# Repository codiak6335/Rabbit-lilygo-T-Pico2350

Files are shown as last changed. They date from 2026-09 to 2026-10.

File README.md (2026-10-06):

# Rabbit controller

The LilyGO T-Pico2350 is being replaced by two separate boards:

- Waveshare RP2350B Plus W, which will run the workout controller.
- Waveshare ESP32-C6-LCD-1.9, which will provide the display and network interface. The connected ESP identifies as an ESP32-C6FH8 with 8 MB flash. USB identifies the chip, but does not distinguish the LCD board variant.

## Inter-board UART wiring

The boards are already connected with three wires. Pin numbers in the left column are **physical header positions** on the RP2350 board, not GPIO numbers.

| RP2350B Plus W | Signal direction | ESP32-C6-LCD-1.9 |
| --- | --- | --- |
| Pin 1, GP0 / UART0 TX | RP2350 → ESP32-C6 | GPIO17 / UART RX |
| Pin 2, GP1 / UART0 RX | ESP32-C6 → RP2350 | GPIO16 / UART TX |
| Pin 3, GND | Common ground | GND |

The existing connection contains TX, RX, and ground; no RTS/CTS wires were specified. See the [Pico-compatible pinout](https://datasheets.raspberrypi.com/pico/Pico-2-Pinout.pdf) and [ESP32-C6-LCD-1.9 documentation](https://docs.waveshare.com/ESP32-C6-LCD-1.9).

## Printable enclosure

The [Rev D resin-window housing](mechanical/resin_housing/README.md) includes PETG body,
lid frame, window retainer and integral PCB standoffs, plus closed and split-wrap TPU strain
relief STLs for 2.3, 3, 3.5 and 4 mm cable jackets. It uses a cast clear resin
window, a silicone cord lid seal and two oversized cable entries for adhesive
sealing. Editable dimensions, print-fit coupons and assembly instructions are
included. The 82 × 128 × 33.1 mm prototype matches the `rev_d_case` 60 × 100 mm
PCB and its offset mounting hole, with the display centered, LED cable entry at
the top and power cable entry at the bottom. The captured KiCad reference is
checked during regeneration. Physical fit and splash/submersion qualification
remain to be performed.

## Current firmware status

The checked-in C++ firmware now targets this three-wire link. The RP2350 uses UART0 on GP0/GP1 without the LilyGO I²C expander startup; the ESP32-C6 uses UART0 on GPIO16/GPIO17 and sends its console output through USB Serial/JTAG. The ESP currently joins the provisioned `beaver` network and keeps `Rabbit-Test-6905` available as a fallback AP. The LCD shows live workout status and the Beaver DHCP address. The checked-in Coach On Deck browser UI is served at `/`, with repeatable pace/sprint set commands and NVS-backed saved sets; `/test` retains the manual diagnostics page. DeckScript plan transfer and surge pacing are flashed and passed paired-device HTTP/UART smoke tests; full browser and pool-side acceptance, external LEDs/audio, protected configuration editing, and hardware qualification remain unfinished. See [firmware/README.md](firmware/README.md) for build and diagnostic commands.

On this development host, the RP2350 appears as `/dev/ttyACM0` and the ESP32-C6 as `/dev/ttyACM1`. With the C++ firmware flashed, their stable serial-device names are:

```text
/dev/serial/by-id/usb-Raspberry_Pi_Pico_509E0DF26DCF56B6-if00
/dev/serial/by-id/usb-Espressif_USB_JTAG_serial_debug_unit_CC:BA:97:F2:69:04-if00
```

The 2026-09-25 paired-device smoke test passed: the ESP32-C6 USB console
reported `Rabbit RP2350 UART link: ready`, and the RP2350 USB `status` command
reported decoded UART requests and responses. The latest station/AP test joined
`beaver` at `192.168.0.178` and returned HTTP 200 for `/`, the browser assets,
pool and saved-set data, and `/api/set-status`. That DHCP address may change;
use the address displayed on the LCD. The fallback AP remains at
`http://192.168.4.1/` after joining `Rabbit-Test-6905`.

## Bluetooth speaker audio

Open **Deck tools → Audio output** in the ESP32 web interface. Audio uses the
same menu-row and Back-button navigation as the other settings.
Choose **Bluetooth speaker** to replace the buzzer or **Buzzer + speaker** for
both outputs. Output selection applies immediately. The volume slider applies
changes automatically as you move it; there is no Save button. Volume is 0–100
and saved volume is preserved. A GPIO active buzzer has a fixed level and is muted
at 0%.

The screen uses a familiar Bluetooth device picker: **My devices** keeps up to eight saved
speakers, including ones that are off or disconnected. Tap a saved device to reconnect
without scanning. Selecting another speaker, closing the page, or restarting either
board keeps all saved devices and their sound confirmations. **Forget** removes only
the device beside that control; forgetting an inactive device keeps the active speaker connected. To add a speaker:

1. Tap **Add speaker** to show **Nearby devices** and pairing instructions.
2. Power on the speaker and hold its Bluetooth button until the pairing indicator
   flashes. Disconnect it from your phone if needed. Tap **Scan** when ready.
   [MEGABOOM 3 pairing instructions](https://support.logi.com/hc/en-gb/articles/18601350410775-Getting-Started-MEGABOOM-3).
3. Tap the desired device in the list to connect directly. Bluetooth addresses
   distinguish devices with identical names; unnamed audio devices can also connect.
4. Once **Connected**, tap **Test 3 beeps**. Adjust volume and test again if needed.
5. Tap **I heard them** to record your sound confirmation. **I didn’t hear them**
   shows guidance to raise volume and repeat the test without confirming.

A scan searches Bluetooth Classic audio devices for about 20 seconds, then resolves
missing names, with a 45-second overall limit. It holds up to 16 devices. **Scan again**
starts fresh; **Stop scan** keeps the current results. Scanning keeps the existing
speaker association and output settings. A rejected Connect request changes neither
output nor volume. An unsuccessful or cancelled new connection retains the previous
saved speaker. **Close** or the screen's Back button stops discovery and cancels an unfinished
connection. Tap the saved speaker to reconnect. An unavailable saved speaker's
automatic reconnect does not block adding another device.
Setup/testing require an idle workout; discovery, connection, and active tests block
workout start. Errors remain visible until the next action.

Bluetooth Classic A2DP/SBC and AVRCP volume control run on the **RP2350B Plus W's CYW43439**.
The ESP32-C6 serves the UI and forwards commands over the existing UART link.
The workout's existing Audio choice gates the same beep signal for both outputs.
Bluetooth speaker buffering adds playback delay; pool-side timing still needs qualification.
While Bluetooth output is connected and unmuted, the RP2350 keeps A2DP streaming and
sends a quiet one-second 80 Hz maintenance pulse every 30 seconds, starting on connection.
The pulse is 1/128 of the workout tone's amplitude and fades in and out to avoid clicks.
It also runs between reps with five- or ten-minute gaps and while idle, to address
speakers that power down despite receiving silent packets. Workout/test beeps take
priority. Volume 0 mutes the pulse; Off, buzzer-only output, or Disconnect stops it.
The exact signal level needed to reset a speaker's inactivity timer is model-dependent;
the MEGABOOM's physical long-gap check remains to be verified. The keep-alive build
is flashed on the RP2350. Three native suites pass, including eleven-minute PCM
checks with five- and ten-minute rep gaps; a round trip through the actual Bluedroid
SBC encoder/decoder preserves the quiet pulse. Live UART/HTTP checks retained both
saved speakers and 49% volume, with the Samsung streaming and no fault recovery reported.
The buzzer remains available if a verified `RABBIT_AUDIO_PIN` is configured.
The development build has that pin disabled.

Output mode, volume, the selected speaker, the saved-device list, each device's sound
confirmation, and pairing keys persist on the RP2350. A full saved-device list does
not evict older speakers: forget one before adding another. Upgrading imports earlier
pairing keys, including devices replaced by the old single-speaker setting. Those keys
contain addresses only; names are recovered when the devices are reachable, and an
old confirmation overwritten by the previous firmware cannot be reconstructed. Settings saves wait until the workout is idle; the API reports pending
saves and the speaker's acknowledged volume. A saved speaker reconnects automatically
while idle when Bluetooth output is enabled. Disconnect suppresses reconnect until
requested again (or the controller restarts); Forget removes the association and its
link key. Confirmation requires a completed test on the currently streaming speaker;
a disconnected or interrupted test cannot be confirmed.

ESP32 HTTP API (commands return current audio status; Devices returns a discovery page):

| Method | Route | Body / query |
| --- | --- | --- |
| GET | `/api/audio/status` | none |
| GET | `/api/audio/saved?offset=0` | saved devices, offset 0–8; up to four results per page |
| POST | `/api/audio/config` | `{"mode":"bluetooth","volume":50}`; modes `off`, `buzzer`, `bluetooth`, `both` |
| POST | `/api/audio/scan` | empty |
| GET | `/api/audio/devices?offset=0` | offset 0–16; up to four results per page |
| POST | `/api/audio/scan-stop` | empty |
| POST | `/api/audio/connect` | `{"address":"C0:28:8D:DC:C9:3D","mode":"bluetooth","volume":49}`; scanned or saved address, mode `bluetooth` or `both` |
| POST | `/api/audio/test` | empty |
| POST | `/api/audio/confirm` | empty; only after a completed speaker test |
| POST | `/api/audio/disconnect` | empty |
| POST | `/api/audio/forget` | `{"address":"C0:28:8D:DC:C9:3D"}` removes that saved speaker; empty body removes the selected speaker |
| POST | `/api/audio/pair` | Legacy exact-name pairing; `{"name":"MEGABOOM 3"}`, empty body uses that name |

Status includes `mode`, `volume`, `connection`, `name`, `address`, `supported`,
`buzzerAvailable`, `paired`, `volumeConfirmed`, `actualVolume`, `testActive`,
`settingsPending`, `soundConfirmed`, `workoutRunning`, and `lastError`.
`actualVolume` is null until acknowledged. Device pages include `scanning`, `full`,
`total`, `devices` (name/address/rssi), and `next` (next offset or null). Saved pages
include `total`, `full`, `devices` (name/address/soundConfirmed), and `next`.
Invalid payloads return 400, unavailable/busy commands 409, unavailable Bluetooth 501,
and a failed UART exchange 503. Scan and Connect are asynchronous; poll Devices and
Status respectively. UI requests have an eight-second response timeout. Slider changes are debounced
200 ms and sent in order; the final slider value is applied even if it changes
while an earlier request is in flight. Output selections apply immediately.

The RP2350 UART API uses the existing version-1 CRC/COBS frames and Hello session.
Message IDs 12–17 remain AudioStatus, AudioConfigure, AudioPair, AudioDisconnect,
AudioTest, and AudioForget. IDs 18–22 add AudioScan, AudioDevices, AudioConnect,
AudioConfirm, and AudioScanStop. IDs 23–24 add AudioSaved and AudioForgetDevice.
Saved takes a one-byte offset; ForgetDevice takes a six-byte address. Configure carries mode/volume bytes; legacy Pair
carries 1–48 name bytes without NUL/control characters. Devices takes a one-byte
offset; Connect takes `[address[6], mode=2|3, volume=0..100]`. Other commands have
empty payloads. Success returns AudioStatus except Devices, which returns AudioDevices.
Request/session IDs are preserved; failures use the existing Reject format.
The status payload remains `[version=1, mode, volume, connection, flags, actualVolume,
lastError, nameLength, address[6], name[nameLength]]`. Connection values 0–6 are
disabled, idle, scanning, connecting, connected, streaming, error. Flag bits 0–7
are supported, buzzer available, paired, volume confirmed, test active, save pending,
sound confirmed, workout running. Unknown actual volume is 255.
Devices payload is `[version=1, scanning, full, total, offset, count, records...]`;
Saved uses the same page header with scanning=0 and replaces RSSI with a 0/1 sound-confirmed byte.
Discovery records are `[nameLength, address[6], signedRssi, name[nameLength]]` (RSSI 0 means
unknown). Four maximum-length records fit in 230 bytes. UART retries reuse IDs and
cannot restart scans, connections, tests, or confirmations. Version-2 audio settings
retain compatibility with previously saved version-1 settings and Bluetooth keys.

Radio GPIOs are GP36 (enable), GP37 (data/host wake), GP38 (CS), and GP39 (clock),
verified against the [Waveshare schematic](https://files.waveshare.com/wiki/RP2350B-Plus-W/RP2350B-Plus-W.pdf).
The LED output uses PIO1 to keep its low GPIO range separate from the radio's high GPIOs.
Large LED/UART buffers reside in static RAM; the foreground stack reserves 4 KiB.
The radio uses foreground CYW43 polling so Bluetooth callbacks and UART commands share
one execution context. Both AVRCP roles are initialized to handle the speaker's control
messages. A four-second watchdog recovers a stalled controller; USB `status` reports
the last recovery stage and captured fault location.
Pairing/settings use the SDK's two flash TLV banks near the end of the 16 MiB flash;
avoid erasing that storage when preserving saved audio settings.

The 2026-10-04 saved-device build is installed on both boards. Native protocol/workout
checks pass (2/2), including saved-list storage validation, pagination, retaining
multiple speakers, and forgetting one device without removing another. Mobile browser
checks cover retained device lists, reconnecting without a scan, per-device Forget,
automatic volume/output changes, connection errors, sound confirmation, workout gating,
scan cancellation, and Back navigation. The installed ESP32 UI displays both the
Samsung Soundbar MS650 and the recovered MEGABOOM pairing, with separate Connect/Forget
controls; the disconnected MEGABOOM remains listed after a page reload. A further
RP2350 reboot retained both records, the Samsung sound confirmation, selected speaker,
and 49% volume; the soundbar resumed streaming. The MEGABOOM's old link key contains
its address but not the name or confirmation overwritten by the old single-device
setting. Earlier live checks verified automatic MEGABOOM volume changes and real
discovery/cancellation. Pool-side latency remains to be qualified. The ESP32 address
for these checks was `http://192.168.0.166/`; use the current LCD address if DHCP changes it.

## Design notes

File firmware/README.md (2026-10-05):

# Native firmware

This directory contains the in-progress production replacement for the
MicroPython controller. The existing Python implementation remains the
behavioral reference until hardware qualification is complete.

## Layout

- `core/`: allocation-free-at-run-time workout validation, pool geometry, and
  scheduler. It has no SDK, file, socket, or sleep dependency.
- `protocol/`: bounded COBS/CRC UART frames and transactional plan-transfer
  buffer shared by the two processors.
- `host/`: desktop executable using the same portable core.
- `rp2350/`: Pico SDK application, local-stop loop, and WS2812 PIO/DMA output.
- `esp32/`: ESP-IDF application boundary for the C6 HTTP/network process.

## Build the portable code

Until CMake is installed, the host checks can run directly with the compiler:

```sh
mkdir -p /tmp/rabbit-native-build
c++ -std=c++17 -Wall -Wextra -Wpedantic -Wconversion -Wshadow \
  -Ifirmware/core/include -Ifirmware/protocol/include \
  firmware/core/src/pool_geometry.cpp firmware/core/src/workout_engine.cpp \
  firmware/protocol/src/framing.cpp firmware/protocol/src/workout_service.cpp \
  tests/native/test_main.cpp \
  -o /tmp/rabbit-native-build/rabbit_native_tests
/tmp/rabbit-native-build/rabbit_native_tests
```

With CMake, build the same targets from the repository root using the supplied
host presets:

```sh
cmake --preset host-debug
cmake --build --preset host-debug
ctest --test-dir build/host-debug --output-on-failure
```

Run the sanitizer configuration separately:

```sh
cmake --preset host-sanitize
cmake --build --preset host-sanitize
ctest --test-dir build/host-sanitize --output-on-failure
```

## RP2350 build

Use the exact Pico SDK and ARM toolchain listed in `toolchains.lock`. The external Rabbit
LED and audio wiring is unverified, so both are disabled by default. Supplying a
pin is a board-qualification step, not a default production configuration.

```sh
cmake -S firmware/rp2350 -B build/rp2350 -G Ninja \
  -DPICO_SDK_PATH=/absolute/path/to/pico-sdk
cmake --build build/rp2350
```

The project defaults to the Waveshare RP2350B Plus W board profile in
`rp2350/boards/`. The generated UF2 appears under `build/rp2350`.
External LED, audio, and local-stop pins remain disabled until their wiring is
verified.
The Pico SDK's generated PIO header is compiled as C++20; the portable engine
and RP2350 application sources remain C++17.

## RP2350 USB diagnostics and UART service

The RP2350 image exposes a USB CDC console after boot. Connect at `115200` baud
and expect `Rabbit RP2350 diagnostic firmware ready`. The bounded commands are
`help`, `status`, `led`, `audio`, and `off`. `led`, `audio`, and local stop
intentionally report unavailable until their physical pins are verified and
supplied at build time. The same image runs the bounded UART0 service at
115200 baud. It accepts a
session handshake plus `PrepareBegin`, `Start`, `Stop`, `Cancel`, and `Status` frames;
COBS framing, CRC, request IDs, and session IDs are enforced. The RP2350 uses
UART0 on physical header pins 1/2 (GP0 TX/GP1 RX), connected to ESP32-C6
GPIO17 RX/GPIO16 TX, with a shared ground on RP2350 header pin 3. No hardware
flow control is wired. The initial
prepare payload is 13 bytes: flags, followed by big-endian `distance_mm`,
`target_ms`, and `interval_ms` fields. The 21-byte set payload adds big-endian
repetitions, final-rep target, and surge percentage. This supports 1–256
whole-pool pace repetitions and a continuous sprint loop. A compiled DeckScript
plan uses checksummed `PrepareBegin`/`PrepareChunk`/`PrepareCommit` frames and a
bounded 12 KiB binary plan. The Pico validates and runs swim, rest, and activity
steps, including continuous loops, per-rep progression, surge, and negative
splits. The base 28-byte UART status frame includes remaining milliseconds,
cycle, set count, current distance and target, and a continuous-mode flag;
DeckScript status appends the current step, strategy, swim count, and bounded
name/label text. External LED pin assignment and calibrated physical geometry
are still unverified.

## ESP32-C6 build

Install and source the exact ESP-IDF release in `toolchains.lock`, then build
in this directory:

```sh
cd firmware/esp32
idf.py set-target esp32c6
idf.py build
```

The ESP application configures UART0 on TX GPIO16/RX GPIO17 without hardware
flow control. Its console uses USB Serial/JTAG so application logs do not enter
the interprocessor link. At startup it probes RP2350 status and reports the
result on its USB console. The onboard 170×320 ST7789V2 LCD displays the live
workout phase, distance, rep count, countdown, and IP address. The ESP polls
RP2350 status for this display and the webpage's set details, so an ESP restart
does not reset the visible rep total. It establishes/re-establishes a session and forwards the
bounded vertical slice through `POST /api/workout/prepare`,
`POST /api/workout/start`, `POST /api/workout/stop`, the legacy quick-set
`GET /prep`, `GET /start`, `GET /startsprint`, `GET /stop`, `GET /cancel-prep`,
and `GET /api/set-status`. The modern prepare route accepts an optional JSON object with
`distanceMm`, `targetMs`, `intervalMs`, `audio`, `waitForInterval`, and
`direction: "far-to-near"`; omitted numeric values select a 25-yard,
30-second test swim. A transport failure returns HTTP 503, never a false
success.

The checked-in Coach On Deck page is embedded at `/`; the former manual test
page is at `/test`. CSS, JavaScript, pool definitions, and the DeckScript prompt
are served from the firmware image. Saved sets begin with the checked-in
`db/sets.json` and subsequent browser edits are validated and committed to
ESP NVS. Pool and Wi-Fi editing intentionally return 501; Wi-Fi credentials
are never served by the browser API. Compiled DeckScript 2 plans from the
browser are validated against the embedded pool list and transferred to the
Pico; unsupported or malformed plans return an error rather than a default
swim. The app uses the 1500 KiB single
app partition; upgrading an earlier 1 MiB build requires flashing its new
partition table alongside the app, without erasing NVS.

The ESP currently joins the provisioned `beaver` network while keeping the
`Rabbit-Test-6905` AP available as a fallback at `http://192.168.4.1/`. The
LCD shows the station's DHCP address after connection; on 2026-09-25 this was
`192.168.0.178`, but the address may change. To
provision an existing Wi-Fi profile without putting its password in source or
on the command line, run this from the repository root (requires `pyserial`):

```sh
python3 tools/provision_esp_wifi.py \
  --port /dev/serial/by-id/usb-Espressif_USB_JTAG_serial_debug_unit_CC:BA:97:F2:69:04-if00 \
  --ssid beaver
```

The tool reads `db/wifi.json`, sends the selected credentials over USB, and
stores them in the ESP's `rabbit_net` NVS namespace. The current station/AP
build loads those credentials on boot, updates the LCD when DHCP assigns an
address, and reports the address
as `Rabbit Wi-Fi connected: ...` on USB. The browser UI is then available
at `http://<that-address>/`. Do not log or commit additional credential
copies when provisioning another device.

Full Wi-Fi lifecycle, protected settings, physical LED/audio wiring,
and phone-browser/pool-side DeckScript acceptance still remain
before this can replace MicroPython. See `../docs/cpp-migration-plan.md` for
the acceptance gates and recovery rules.

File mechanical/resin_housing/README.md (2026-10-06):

# Rev D housing with cast-resin viewing lid

Printable housing for the **`rev_d_case` 60 × 100 mm carrier PCB**, with a clear resin window centered over the ESP32 display. The assembled shell is **82 × 128 × 33.1 mm**, excluding the cable boots. Viewed with the screen facing you, the **LED cable exits the top end** and **power enters the bottom end**. Both glands share the case and display centreline at **X = 30 mm**, with internal leads running to J6 and J5. Both entries accept the same relief neck; choose reliefs for **2.3, 3.0, 3.5 or 4.0 mm complete cable jacket diameters**.

This replaces the earlier 88 × 58 mm compact-carrier housing. PCB outline, mounting holes and socket positions are checked against the captured [Rev D KiCad board](reference/Rabbit_Carrier_RevD.kicad_pcb). Module heights, actual LCD datum and sealing still require first-article checks. **Physical fit and leak testing have not been performed; it has no verified waterproof/IP rating.** Print the coupons first, then qualify frequent splashes and brief submersion up to 3 ft.

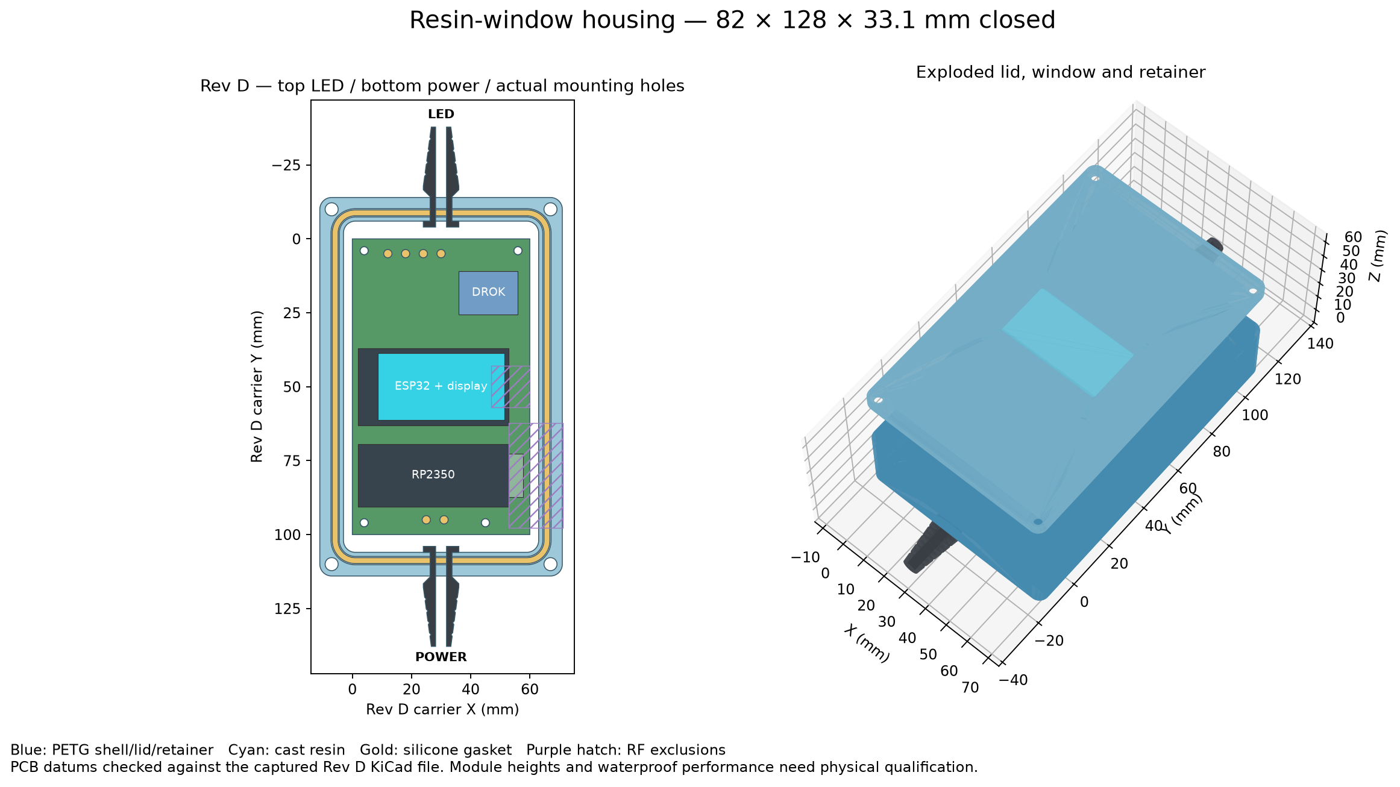
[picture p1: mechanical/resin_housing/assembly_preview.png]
Assembly and plan


## Files and print quantities

All STL dimensions are millimetres. Each STL is already placed on the print bed in its intended orientation. Import at 100% scale.

| Part | Quantity | Material / purpose |
| --- | ---: | --- |
| [Body](stl/body_petg.stl) | 1 | PETG; open side up; blind insert pockets, cord groove and four integral Rev D standoffs |
| [Lid frame](stl/lid_frame_petg.stl) | 1 | PETG; outside face down; doubles as the resin casting frame |
| [Window retainer](stl/window_retainer_petg.stl) | 1 | PETG; sealant groove faces up in the slicer, toward the lid in assembly |
| [Cable entry coupon](stl/cable_entry_fit_coupon_petg.stl) | 1 optional | PETG; reproduces the horizontal bore and 8 mm wall thickness |
| [Resin casting coupon](stl/resin_cast_fit_coupon_petg.stl) | 1 optional | PETG; small version of the cast window flange |
| [Coupon retainer](stl/resin_coupon_retainer_petg.stl) | 1 optional | PETG; tests mechanical retention and the resin/PETG seal |
| [Unused entry plug](stl/unused_entry_plug_tpu.stl) | As needed | TPU; seal into any unused entry |
| Cable reliefs below | 1 per cable | TPU; inside flange on the bed, cable bore vertical |

| Cable jacket outside diameter | Closed relief | Split wrap relief | Nominal bore |
| --- | --- | --- | ---: |
| 2.3 mm | [STL](stl/strain_relief_2_3mm_closed_tpu.stl) | [STL](stl/strain_relief_2_3mm_split_wrap_tpu.stl) | 2.5 mm |
| 3.0 mm | [STL](stl/strain_relief_3_0mm_closed_tpu.stl) | [STL](stl/strain_relief_3_0mm_split_wrap_tpu.stl) | 3.2 mm |
| 3.5 mm | [STL](stl/strain_relief_3_5mm_closed_tpu.stl) | [STL](stl/strain_relief_3_5mm_split_wrap_tpu.stl) | 3.7 mm |
| 4.0 mm | [STL](stl/strain_relief_4_0mm_closed_tpu.stl) | [STL](stl/strain_relief_4_0mm_split_wrap_tpu.stl) | 4.2 mm |

Closed reliefs can be fitted before feeding the cable through. Split wraps open along a 0.4 mm radial seam for already terminated cables; that seam must be filled and sealed. The specified wire sizes refer to the **complete insulated jacket**, not the conductor diameter. A common jacket around multiple conductors needs its own measured relief bore.

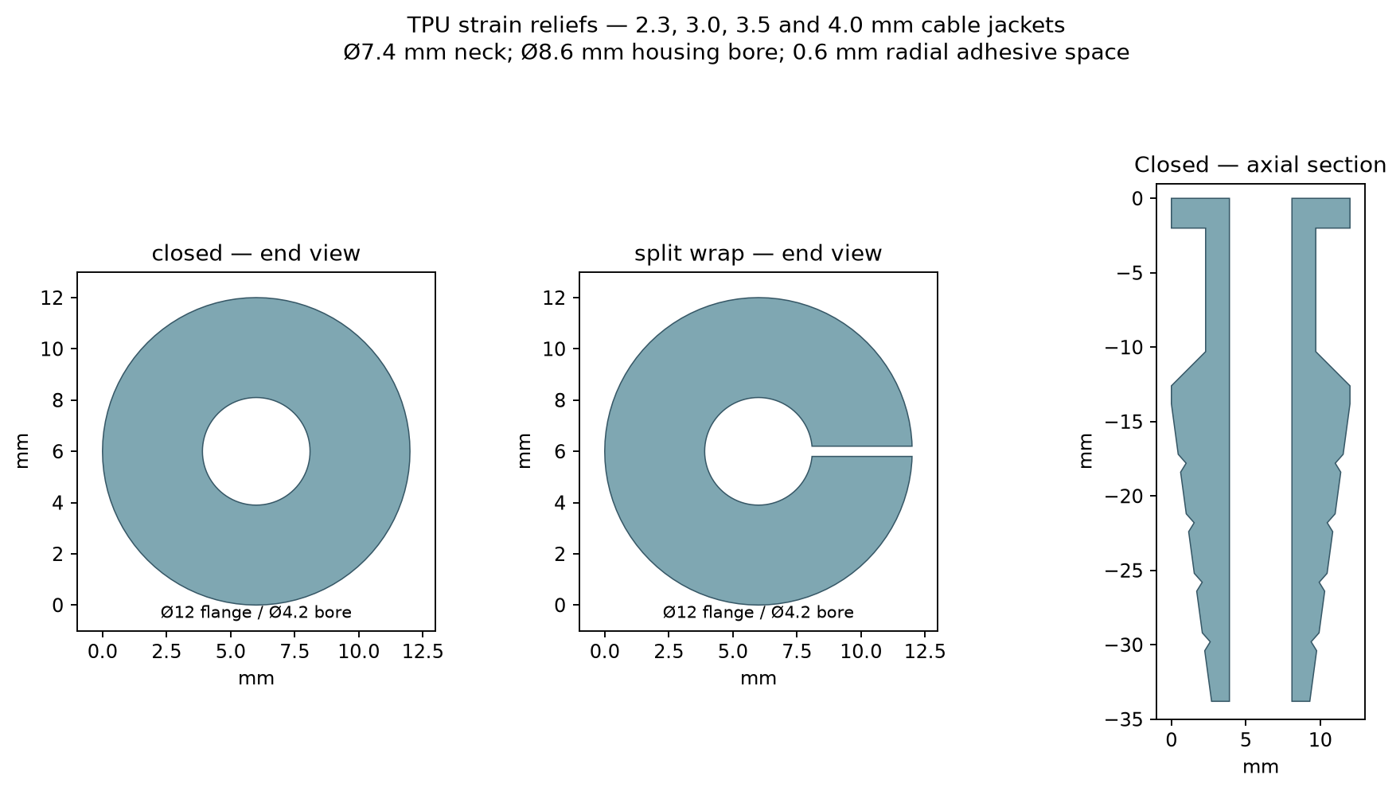
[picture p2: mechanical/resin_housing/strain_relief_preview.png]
Relief cross-sections


## Dimensions and hardware assumptions

See [dimensions.svg](dimensions.svg) for the plan. Coordinates below follow the carrier drawing: X right, Y down; Z up from the outside bottom of the enclosure.

| Feature | Nominal dimension |
| --- | --- |
| Carrier PCB | Rev D, 60 × 100 × 1.6 mm |
| PCB mounting holes | Ø2.7 mm at (4,4), (56,4), (4,96), **(45,96)** |
| Integral standoffs | Ø6 mm, 2.5 mm above the floor; Ø2.0 mm blind pilots for M2.5 plastic-tapping screws |
| PCB underside | Z = 5.5 mm; 2.5 mm clearance over the 3 mm floor |
| Space above PCB | 22 mm to lid; 20 mm under the window retainer |
| Estimated LCD front plane | 18.35 mm above PCB top; 1.65 mm below the retainer, 3.65 mm below the resin |
| Viewing opening | Rev D provisional aperture, 43.5 × 23.5 mm, corner radius 1 mm |
| Viewing opening centre | Carrier X = 30, Y = 50 mm |
| Cast resin | 4 mm thick at the viewing opening; 55.5 × 35.5 × 2.4 mm rear flange, corner radius 3 mm |
| Resin amount | About 6.3 mL net; allow for mixing/cup losses |
| Window retainer | 63.5 × 43.5 × 2 mm; continuous 1.2 mm wide × 0.6 mm deep sealant groove |
| Retainer screw centres | (11,30.25), (49,30.25), (11,69.75), (49,69.75); clear of RF exclusions |
| Cable holes | Ø8.6 mm through the 8 mm top and bottom end walls |
| LED entry | Top end (−Y), centered at X = 30; wall spans Y = −14 to −6; cable axis Z = 15 |
| Power entry | Bottom end (+Y), centered at X = 30; wall spans Y = 106 to 114; cable axis Z = 15 |
| Relief neck / collar | Ø7.4 mm neck, 8.3 mm between collar faces; Ø12 mm collars |
| Glue clearance | 0.6 mm radial gap around relief neck; 0.1 mm nominal radial gap around cable |
| Relief length | 33.8 mm total; approximately 24 mm projects outside the case |
| Main gasket | 2 mm silicone cord in a 2.8 × 1.5 mm groove; nominal 25% squeeze at the flat rim stop |
| Gasket centreline length | About 367 mm; cut/join to the actual printed groove |

The ESP board envelope is 51 × 26 mm at carrier X=1.86, Y=37; the RP2350 is 51 × 21 mm at X=1.86, Y=69.5, with a 4.92 mm radio extension to the right. The visible display centre is (30,50), while the ESP PCB centre is (27.36,50). The 2.64 mm offset comes from the Rev D case datum: J3 pad 1 + (26.77,8.89). The active display is 42.72 × 22.70 mm and clears the modeled opening. Confirm the first article against [Waveshare dimensions](https://docs.waveshare.com/ESP32-C6-LCD-1.9); the Rev D documentation flags the manufacturer archive's S3-named mechanical model as provisional for the C6 board.

The four standoffs match the carrier's real mounting holes, including the deliberately offset lower-right hole. USB connectors remain enclosed; for USB service, remove the lid and lift the controller from its sockets to give the plug room. Both end-wall glands are centered at X=30; route their internal leads to J6 at the top and J5 at the bottom. The lid and base remain intact. Verify actual cable jacket diameters, collar installation, wiring bends, socket engagement and assembled module height before printing the full body. The LCD face height is the Rev D estimate; RP and DROK heights are conservative illustrative reservations, not measured assemblies.

Both ends have 6 mm clearance for the inner cable collars and wiring. Side clearance accommodates the resin flange/retainer; the 8 mm rim provides room for the cord seal and lid screws outside it. The shell adds about 24 mm of external boot projection at each end.

The RP RF exclusion is (52.78,62.25)–(71.28,97.75); the ESP exclusion is (47,43)–(60,57). Case fasteners are checked against both regions, and the lower retainer screws are moved inward accordingly. The RP exclusion extends 11.28 mm past the PCB edge: the plastic wall may occupy this area, but keep wires, added electronics, metal mounting hardware and conductive coatings clear.

## Materials and fasteners

- PETG for body, lid and retainer; this version is sized for PETG printing. A change to PP requires new fit and adhesive trials.
- TPU, starting with 95A, for reliefs and unused-port plugs. Softer TPU may ease installation, but fit must be checked on the coupon.
- Optically clear two-part casting epoxy suitable for a **4 mm section**, with the manufacturer's mixing ratio and full cure time. For example, read the [clear casting epoxy technical sheet](https://www.smooth-on.com/tb/files/EPOXACAST_690_692_TB.pdf) when choosing resin; optical clarity, sunlight exposure and adhesion need your own coupon trial.
- Flexible neutral-cure sealant compatible with the specific cured resin, PETG, TPU and cable jacket. Confirm adhesion and immersion suitability on the coupons.
- Approximately 380 mm of 2 mm silicone cord, with a sealed end joint, or a custom continuous silicone gasket matching the groove.
- Four M3 heat-set inserts, nominal 4.6 mm outer diameter × 4 mm long; the body pilot pockets are Ø4.4 × 4.2 mm. Match the actual insert supplier's hole recommendation before printing.
- Four M3 × 8 mm button-head machine screws. The lid has Ø6.4 × 1.8 mm head recesses; use heads that fit them.
- Four M2 × 5 mm plastic-tapping screws for the window retainer, using Ø1.7 mm blind pilots. The casting coupon uses four more M2 × 5 screws temporarily.
- Four M2.5 × 6 mm plastic-tapping screws for the PCB, using its existing Ø2.7 mm clearance holes and the standoffs' Ø2.0 mm blind pilots. Their nominal engagement is 4.4 mm, leaving about 1.1 mm of solid base underneath. Qualify thread grip before installing the board.

## Printing

Start with a 0.4 mm nozzle, 0.2 mm layers, six PETG perimeters and solid floor/lid layers. Use at least 15 bottom layers for the 3 mm floor, and 100% infill for the frame and retainer. Use four TPU perimeters and 100% infill; print the reliefs upright as supplied. These are starting settings, not a waterproof process specification.

The body and cable coupon have horizontal circular bores. Inspect sagging and clean the bore gently; qualify relief fit using the coupon printed with the same profile. The other parts have no enclosed support cavities. Keep supports out of the cord groove, casting pocket and cable bore. A small brim can help the upright coupon and TPU parts.

Inspect printed seams and layer bonding. Seal any porosity with a compatible thin coating and keep gasket lands flat and clean. FDM watertightness depends on the print process; see [Prusa's watertight-print experiments](https://blog.prusa3d.com/watertight-3d-printing-pt1-vases-cups-and-other-open-models_48949/). Do not treat a watertight STL mesh as evidence of a watertight print.

## Casting and assembly

1. Print the cable and resin coupons and the required relief diameter. Check the fit on the actual cable, collar insertion, glue filling, resin cure and sealant adhesion. The coupon has a 20 × 14 mm viewing opening with the same 4 mm optical thickness and 2.4 mm rear flange construction.
2. Print the full lid. Its outside face is the flat face that was on the print bed; its inside face contains the larger stepped casting pocket. Clean the pocket and prepare the PETG bond surfaces as required by the resin/sealant supplier.
3. Place the outside face **down on flat, release-treated glass**, leaving the stepped inside pocket facing up. Hold the frame flat and seal the temporary mould contact so resin cannot escape under it. Keep mould release off the permanent bond surfaces. Pour through the central opening and fill the larger rear pocket flush with the inside face. The glass forms the smooth optical face; the wider pocket forms the retaining flange. Cast with the electronics removed and allow full cure.
4. Clean flash from the window and inspect it. Fill the retainer's continuous groove with compatible sealant. The groove straddles the resin/PETG seam when the ring is installed. Put the ring against the inside lid, **groove toward the lid**, and use the four M2 × 5 screws. Tighten gently and cure the sealant. The rear ring supports inward water pressure on the resin flange; the outer PETG ledge prevents outward movement. The sealant closes the seam.
5. Install the four M3 inserts flush with the body rim. Avoid disturbing the adjacent cord groove. Fit the silicone cord, sealing its joined ends; its compression is set by the lid touching the flat rim.
6. Fit each TPU relief with the smaller flat flange inside and the tapered boot outside. Try folding the inner TPU collar through the coupon before committing to the case. Closed reliefs are installed before feeding the cable; split wraps can be opened around it. Seal the entire neck-to-wall annulus, cable-to-bore gap, and split seam over the collar/neck region. Use continuous intact cable jacket at the seal. Cure fully. Seal a TPU plug into an unused entry.
7. Leak-test the empty enclosure with dry paper inside: frequent splashes, then brief submersion progressing to the intended maximum of 3 ft. Gently move the cables during testing and inspect the window seam, cable entries, cord joint and printed walls. Fix and retest any ingress before installing electronics.
8. Place the Rev D carrier on the four standoffs with J6 at the LED end and J5 at the power end. The lower-right hole is at X=45, not X=56. Use four M2.5 × 6 screws through the PCB holes. Keep cable routing away from the antenna zones. Check real display height/alignment, cable bends and clearance under the retainer. Close using the four M3 lid screws evenly until the rim meets; avoid crushing the PETG or over-tightening plastic-tapping screws.

## Editing and regenerating

The editable design is [parameters.json](parameters.json) plus [generate_resin_housing.py](generate_resin_housing.py). Change assembled clearance, resin window dimensions or cable positions there. PCB datums are tied to the captured [Rev D board](reference/Rabbit_Carrier_RevD.kicad_pcb), copied from `/home/codiak/hgfs/vmshared/Rabbit_Carrier/rev_d_case/`. The [original case plan](reference/RevD_Case_Plan.svg) and [display alignment](reference/RevD_Horizontal_Alignment.svg) record the mechanical datum assumptions. The original plan's wiring arrows mark PCB connection positions; this housing uses centered glands as specified in `parameters.json`. The SHA-256 identifies the exact PCB input. A different board revision requires a new source reference and reviewed mounting/module datums.

The generator checks source checksum, PCB outline/thickness, all four mount holes/drills, socket rows, DROK origin, module placement and LCD centre against the KiCad file. It exports 15 STLs, the dimension drawing, previews and [validation.json](validation.json), checking connected watertight meshes, winding, exported STL reloads, assembly collisions, print-bed placement, LCD visibility, correct top LED/bottom power assignment and case-metal clearance from both RF exclusions. Both window and carrier screw holes are blind; only the two sealed cable holes open through the shell.

```sh
python3 -m venv /tmp/rabbit-housing-venv
/tmp/rabbit-housing-venv/bin/pip install -r mechanical/resin_housing/requirements.txt
/tmp/rabbit-housing-venv/bin/python mechanical/resin_housing/generate_resin_housing.py
```

To generate a variant without overwriting these files:

```sh
/tmp/rabbit-housing-venv/bin/python mechanical/resin_housing/generate_resin_housing.py \
  --parameters /path/to/variant.json --output /tmp/rabbit-housing-variant
```

The obsolete corner-clip STL from the compact-carrier design has been removed. Use this release's complete body/lid/retainer set together. A fit-check failure is a reason to inspect the changed geometry. The released files passed all geometric checks with the supplied parameters. Sealing, screw grip, resin adhesion and print tolerances still require the physical trials described above.

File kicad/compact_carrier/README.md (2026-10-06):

# Compact two-board carrier — placement study

Open [`rabbit_compact_carrier.kicad_pro`](rabbit_compact_carrier.kicad_pro) in KiCad. This is a new project in the Rabbit repository; [`../proto`](../proto) remains untouched as a visual/mechanical reference. `proto` has two Pico 2 W footprints and cannot be used as the electrical design for the RP2350B-Plus-W and ESP32-C6-LCD-1.9 pair.

The first candidate outline is **88 × 58 mm**, compared with about 89.2 × 57 mm for `proto` and 115 × 92 mm for the earlier powered-carrier draft. The two existing modules and all future components are intended to mount on the **front/top face**. This does not mean single-layer copper: the file starts as a two-layer PCB. Both module USB-C sockets face the left board edge. The right-hand rectangles reserve space for the DROK, 12 V input, and LED/buzzer connection, but are **drawings, not populated footprints**.

J1/J2 represent the ESP's two 1×20 socket rows; J3/J4 represent the RP board's rows. The three verified UART/GND nets are assigned to the first three pads of J1/J3 but **are not routed**. All other pads are intentionally unconnected. The local `Rabbit_Carrier.pretty` footprint library is included so the project is self-contained. Its row pitch and pad size come from the prior carrier draft; the actual two boards, socket height, pin orientation, body envelopes, LCD overhang, antenna clearance, and USB cable clearance still need a full-size print/physical fit check.

**PLACEMENT ONLY — DO NOT FABRICATE OR POWER.** There is no KiCad schematic, safe power/USB coexistence circuit, protection circuitry, connector footprints, mounting-hole solution, DRC sign-off, or fabrication output. The compact right-hand reserve may need to grow when those parts are selected. In particular, do not connect DROK 5 V to either module while a PC USB cable is attached until the power-isolation design has been captured and verified.

Next design gate: confirm whether both module USB connections must remain connected to computers while the 12 V/DROK supply powers both boards. That choice determines the power/USB architecture and whether this outline can be retained.

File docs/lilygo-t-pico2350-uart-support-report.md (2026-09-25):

# Support Request: T-Pico2350 ESP32-C6 / RP2350 UART Failure

## Summary

We are requesting assistance with the communication link between the ESP32-C6 and RP2350 on a LilyGO T-Pico2350 / T-PicoPro. Both processors boot and can be flashed independently through the reversible USB-C connector, but they do not communicate over their inter-processor UART connection.

This report includes results from our own test firmware and, independently, from the factory firmware supplied in the LilyGO T-Pico2 repository. No knowledge of our application is required to investigate this issue.

## Board and Symptoms

- Board: LilyGO T-Pico2350 / T-PicoPro with RP2350A and ESP32-C6.
- The reversible USB-C connector selects either the RP2350 or ESP32-C6 USB interface as expected.
- The ESP32-C6 is detected as `ESP32-C6FH4` and accepts firmware flashes successfully.
- The RP2350 enters BOOTSEL mode and accepts UF2 firmware successfully.
- Our ESP32-C6 test firmware can run a SoftAP and HTTP server, but requests requiring an RP2350 response return `503 Service Unavailable`.
- The charging-status LED blinks rapidly with no battery connected. Please confirm whether this is expected on this board revision.

## Independent UART Test Firmware

To verify the link directly, we configured our test firmware using the following inter-chip pin mapping:

| RP2350A | ESP32-C6 |
| --- | --- |
| GPIO28 TX | GPIO6 RX |
| GPIO29 RX | GPIO7 TX |
| GPIO26 CTS | GPIO5 CTS |
| GPIO27 RTS | GPIO4 RTS |

The RP2350 was configured for UART0 on GPIO28/GPIO29. The ESP32-C6 was configured for UART1 at 115200 baud on GPIO7/GPIO6. The ESP32-C6 reports successful writes of complete 19-byte UART protocol frames, but RP2350 diagnostics see no complete frames and no replies are returned.

## Factory Firmware Reproduction

To determine whether the issue was specific to our software, we flashed the official LilyGO factory firmware supplied in the T-Pico2 repository to both processors:

1. Flashed `firmware/factory_ESP32C6-4MB.bin` to the ESP32-C6 at address `0x0`. The write and verification completed successfully.
2. Flashed `firmware/T-Lilygo-rp2350_ESP32C6_V1.2.uf2` to the RP2350 BOOTSEL drive. The copy completed successfully.
3. Opened the RP2350 serial output at 115200 baud.

The factory RP2350 firmware reported:

```
WiFi Module is not online !
```

This occurred while both LilyGO factory images were installed. We then restored our own test firmware.

## Requested Support

Please advise whether this result indicates a hardware fault, an affected board revision, or an additional required hardware or firmware initialization step. In particular, please confirm:

1. The correct ESP32-C6 ↔ RP2350 UART pin mapping and UART peripheral settings for this board revision.
2. Whether the factory RP2350 firmware should detect the ESP32-C6 after the supplied factory ESP32-C6 image is flashed, and whether `WiFi Module is not online !` is an expected result.
3. The meaning of the rapid green charging-status LED blink when no battery is attached.
4. Whether the board should be replaced under warranty based on the failed factory inter-processor test.

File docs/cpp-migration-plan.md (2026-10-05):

# Rabbit C++ migration plan

Review date: 2026-09-17. Source baseline: `2c9afe7`, branch `c++`.

Historical review: this plan predates the separate Waveshare boards and the
checked-in C++ firmware. Use the root [README](../README.md) and
[firmware README](../firmware/README.md) for the current hardware and build
settings.

This is a review and implementation plan; no firmware has been ported or flashed. The working assumption is **RP2350 and ESP32-C6 cooperating on one LilyGO T-Pico2350/T-Pico2 board**. Separate standalone RP2350 and ESP32 products would require additional board and networking adapters. Confirm the physical board revision before selecting pins or flashing images.

## Recommendation

Use C++17 for application code, Raspberry Pi Pico SDK/CMake on the RP2350, and ESP-IDF on the ESP32-C6. Keep the existing browser UI and JavaScript DeckScript compiler. Move the workout engine into a portable C++ library, first exercised on the desktop, then deployed to the RP2350.

The RP2350 owns workout state, time, LED output, audio, local controls, and its display. The ESP32-C6 owns networking, HTTP, browser assets, credentials, and persistent configuration. Transfer complete prepared plans across UART; execute them entirely on the RP2350.

```mermaid
flowchart LR
    Browser[Browser UI and DeckScript compiler] <-->|HTTP and JSON| ESP[ESP32-C6: Wi-Fi, API, storage]
    ESP <-->|Versioned UART commands and status| RP[RP2350: workout engine and clock]
    RP --> LEDs[PIO and DMA LED output]
    RP --> Local[Display, audio, local stop]
    Core[Portable C++ engine] --> RP
    Core --> Host[Desktop simulator and tests]
```

Pico SDK supports C/C++, CMake, and CLion; its hardware APIs cover PIO and DMA. ESP-IDF supports C++ and supplies an HTTP server for ESP32-C6. These are two firmware builds with a shared library and protocol, not one cross-compiled image. Pin tested SDK/toolchain versions during bring-up. [Pico SDK](https://www.raspberrypi.com/documentation/microcontrollers/c_sdk.html), [PIO/DMA APIs](https://www.raspberrypi.com/documentation/pico-sdk/hardware.html), [ESP-IDF C++](https://docs.espressif.com/projects/esp-idf/en/stable/esp32c6/api-guides/cplusplus.html), [HTTP server](https://docs.espressif.com/projects/esp-idf/en/stable/esp32c6/api-reference/protocols/esp_http_server.html).

LilyGO's examples use Arduino and can serve as hardware reference tests. A Pico SDK board-support layer requires porting the necessary initialization and drivers; account for that work explicitly. If that effort dominates bring-up, evaluate an Arduino-Pico adapter using the same portable core before changing the application architecture. [Vendor build configuration](https://raw.githubusercontent.com/Xinyuan-LilyGO/Lilygo-T-Pico2/master/platformio.ini).

## Current implementation

| Area | Current source | Migration treatment |
| --- | --- | --- |
| HTTP, configuration, networking, startup | `main.py` (1,258 lines), `microdot.py` | Replace with ESP-IDF services and a compatibility API layer |
| Pool geometry, calibration, pacing, repetitions, LED output | `swimset.py` (712 lines) | Separate pure calculations/state machine from RP2350 drivers |
| Compiled workout validation and execution | `workout_runner.py` (334 lines) | Port semantics into the portable core |
| Cursor, beeps, displays | `ledcursor.py`, `audioalert.py`, `displays.py` | Preserve presentation concepts; replace blocking/hardware implementations |
| Coach UI and compiler | `index.html`, `js/navigation.js`, `js/deckscript.js`, CSS/static files | Retain browser implementation and asset paths |
| Stored data | `db/pools.json`, `db/sets.json`, `db/lastled.dat`; optional device `wifi.json` | Export/import through versioned storage adapters |
| Desktop emulation | `runtime_support.py`, `emulator/`, `emulator.html`, `js/emulator.js` | Reuse viewer concepts and HTTP contract with a native engine |
| Existing checks | `tools/test_*.py`, `tools/test_deckscript.js`, `tools/smoke_emulator.py` | Use as initial behavioral baseline; extend with native and device tests |

There is no checked-in C/C++ implementation or CMake build. The root README is empty. Firmware replacement therefore includes a build/deploy workflow and operating documentation, not just source translation.

## Review findings that affect the migration

These findings come from source inspection unless marked as test results. They are not measurements on the physical board.

| Priority | Finding and evidence | Required treatment |
| --- | --- | --- |
| High | **Existing drivers do not describe the target board.** `displays.py:41` uses a 320×170 parallel ST7789 arrangement with pins up to 48; `displays.py:171` selects hardware using module availability and a machine-name string. `swimset.py:246` uses LED GPIO16; `audioalert.py:12` uses GPIO15. | Define an explicit board profile, including external LED/audio wiring. Bring up the actual LCD, expander, power management, and serial link independently. |
| High | **Pool units and calibration have conflicting assumptions.** `workout_runner.py:175` and `main.py:1002` initialize length as 25; negative-split validation also assumes 25-unit lengths. `swimset.py:440` converts length to feet as yards, although `PoolData.get_corrected_bcm()` supports a 50-metre label. That method shifts segment indices against `lastled.dat`, while timing construction starts at fixed `FIRSTPIXEL=174`. | Introduce explicit units, actual pool length, strip pixel count, and calibrated physical distance-to-pixel mapping. Validate every imported range. Define expected results for each supplied pool before porting. |
| High | **Stop responsiveness is blocked by work inside the pacing loop.** `audioalert.py:18` sleeps through a triple beep for about 2.15 seconds. `swimset.py:511` can sleep at a turn. `main.py:1070` and `main.py:1204` wait at most two seconds and can then return “Stopped” without verified completion. | Use scheduled audio edges and nonblocking engine transitions. Acknowledge applied stop state, with bounded queues and measured output latency. |
| High | **HTTP handlers and the runner share mutable output/state.** Start has a lock, but calibration/strand handlers can write the same strand while a runner executes; status reads mutable fields. `main.py:1109` onward and `main.py:1152` illustrate the split ownership. | One RP2350 owner processes commands and publishes immutable snapshots. Reject calibration during a run. ESP HTTP tasks never mutate engine state directly. |
| High | **Credential reads bypass admin protection.** The GET branch of `main.py:1014` serves database files before checking `require_admin()`, including device Wi-Fi configuration if present. Startup/profile and POST logging also print credential-bearing data. | Make sensitive reads authenticated, remove secret logging, and return redacted credentials to the UI with explicit keep/replace semantics. Migrate the network-settings editor with this API change. |
| Medium | **Numeric and allocation bounds are incomplete.** Pool validation checks nonnegative pixel indices but does not prove they fit the allocated 910-pixel strand or form usable sections. `save_as_last_led` has no upper bound. Legacy repetition/distance inputs can drive large allocations. | Validate finite numbers, physical bounds, monotonic/nonzero sections, integer metadata, and total memory cost before activating a plan. Validate decoded serial commands as well as HTTP JSON. |
| Medium | **Fractional timing differs across paths.** `main.py:829` divides the fractional digits by 100 regardless of digit count: `30.5` becomes 30.05. Legacy prep then casts durations/intervals to integers. DeckScript accepts fractional numeric seconds. | Adopt one canonical integer time representation and rounding rule; document this as an intentional correction rather than silently reproducing it. |
| Medium | **Reconnect logic is present but not started by this entry point.** `network_watchdog_thread` is defined in `main.py:569`; graph context and a text search show no invocation. Startup reaches `run_control_server` directly. Missing Wi-Fi configuration is also not handled by `read_profiles`. | Implement and test an ESP-IDF Wi-Fi event state machine, bounded reconnect/backoff, and first-boot AP fallback. |
| Medium | **Storage replacement is not always atomic.** `main.py:262` falls back to deleting the old file before renaming the temporary file when `os.replace` is unavailable. | Use storage transactions with recoverable generations and fault-injection tests for interrupted writes. |

GitNexus impact analysis reports `set_bottom_times` as LOW with `prep` as a direct caller participating in six listed flows, and `rep` as LOW with direct callers `loop` and `sprintloop`. Source inspection also shows `WorkoutRunner._initialize_hardware` calling `set_bottom_times` and `WorkoutRunner.run` calling `rep`; these dynamic references are absent from those graph results. Treat graph counts as a lower bound. The behavioral migration risk is high across legacy pace, sprint, and DeckScript workflows even though the individual graph verdicts are LOW.

## Hardware bring-up contract

The vendor identifies an RP2350 with 520 kB SRAM/16 MB flash and an ESP32-C6 with 4 MB flash. The board uses a reversible USB connection for access to the two processors, and RP-side logic controls ESP reset. Preserve recovery access while developing custom ESP firmware. [Vendor board documentation](https://github.com/Xinyuan-LilyGO/Lilygo-T-Pico2).

The following are reference values, not an approved wiring manifest:

| Function | Vendor reference | Bring-up check |
| --- | --- | --- |
| LCD | ST7796, 222×480; SPI MISO4/MOSI7/SCK6, CS8/DC9 | Color order, offsets, orientation, and partial-window updates |
| Shared peripheral I2C | RP GPIO0/1 | Probe expander, PMU, and touch device; confirm addresses and startup order |
| LCD reset/backlight | Expander outputs 0/1 | Confirm polarity and usable backlight control |
| ESP link | RP TX28/RX29; flow-control pins 26/27 | Verify crossed directions and boot/reset behavior on the schematic |
| ESP enable | Expander output 3 | Do not hold ESP in reset during flashing/recovery |
| Local button | RP GPIO23 | Debounced stop and boot behavior |
| External LEDs and audio | Repository uses GPIO16/GPIO15 | Select accessible pins against the actual revision and any HDMI/shared functions |

[Vendor peripheral definitions](https://raw.githubusercontent.com/Xinyuan-LilyGO/Lilygo-T-Pico2/master/examples/Factory/utilities.h), [LCD configuration](https://raw.githubusercontent.com/Xinyuan-LilyGO/Lilygo-T-Pico2/master/lib/TFT_eSPI/User_Setups/Setup214_LilyGo_T_Pico2Pro.h).

Vendor resources contain naming/pin inconsistencies: for example, the README and factory header disagree on the QWIIC UART TX pin. Do not copy those assignments blindly. Record the board silkscreen/revision, schematic revision, verified pin table, LED part/order/rate, level shifting, strip power arrangement, and audio hardware before driver implementation. Do not assume optional external RAM is present or required.

## Compatibility boundaries

Keep these behaviors explicit in shared fixtures:

- Legacy pace and sprint, Near/Far starting direction, audio enabled/disabled, finite and continuous runs, prepare/start/stop/continue/cancel, and calibration tools.
- Legacy `negative_split` changes targets across repetitions; DeckScript `negativeSplit` changes the two halves of each repetition. They must remain separate strategies internally.
- DeckScript 2 `executionPlan` and `compactExecutionPlan`, including optional/default fields and all `s`/`r`/`a` entry shapes. Keep 256 entries, a 12 KiB prepare-request limit, names up to 64 characters, and labels up to 80 characters. Specify UTF-8 byte budgets separately from character counts so C++ buffers do not truncate valid text.
- `hold` is target duration; `on` is start-to-start timing; explicit rest follows completion. Respect `waitForInterval`, including no final send-off wait at a block boundary.
- Stop skips the interrupted swim/recovery; Continue advances to the next step. It is not a pause/resume operation. Existing activity entries clear output and advance immediately rather than waiting for human completion.
- Legacy sprint retains its starting direction per repetition and uses a single beep; ordinary repetitions use the existing triple-beep behavior. Capture initial-start, muted-audio, interval-too-short-for-beeps, final-repetition, and stop-during-beep cases before choosing corrected scheduling rules.
- Preserve calibration overlays where intended: `clear_strand()` currently redraws 15 m markers, so normal stop and fault blackout need distinct output policies.

The browser remains the DeckScript compiler. The controller accepts only validated execution plans; it does not need a C++ parser for the source language. This preserves most of the existing UI investment. [Existing contract](deckscript.md).

Retain URLs, methods, field names, error shapes, and status behavior through compatibility handlers:

| Surface | Endpoints |
| --- | --- |
| Static UI | `/`, `/favicon.ico`, `/css/*`, `/js/*`, `/static/*` |
| Legacy control | `/prep`, `/start`, `/startsprint`, `/stop`, `/cancel-prep` |
| Workouts and status | POST `/api/workout/prepare`, POST `/api/workout/start`, GET `/api/set-status` |
| Configuration | `/loadpools`, GET/POST `/db/pools.json`, `/db/sets.json`, `/db/wifi.json` |
| Calibration | `/IgniteLedLoc/*`, `/saveaslastled/*`, `/LightStrand`, `/ClearStrand`, `/LightSegment`, `/ignitemarkers` |
| Recovery | `/HardReset`, with documented behavior for both processors |
| Desktop diagnostics | `/emulator`, `/api/emulator/state`, `/api/emulator/pool-profile` |

Keep desktop diagnostics available in the native simulator; decide separately whether to expose lightweight equivalents in production. Do not restore arbitrary filesystem access such as a generic database/prototype path server. Use explicit allowlists. Preserve public pool/set reads only if intended, and require admin credentials for writes, controls, and sensitive reads. Legacy mutating GETs can be compatibility aliases; replacement POST controls and same-origin checks can be introduced with coordinated UI changes.

## Native design

### Portable engine

Create small modules for `PoolGeometry`, `PacingPlan`, `WorkoutEngine`, `CursorRenderer`, `AudioSchedule`, and protocol serialization. Use explicit enums/structs, integer microseconds on a monotonic 64-bit clock, explicit distance units, and deterministic rounding of segment durations so they sum to the intended total.

Expose command application and `advance(now)` behavior with bounded work. Suggested internal states are Idle, Prepared, PreStart, Swimming, Resting, Stopping, Stopped, Complete, and Fault. Publish a versioned snapshot for HTTP/display formatting. The engine accepts clock readings and produces output/events; it has no socket, filesystem, SDK, or sleep dependencies.

Start with one RP2350 application owner loop, PIO/DMA output, and bounded display transfers. Reserve the second core until profiling justifies its synchronization cost. Use fixed-capacity storage or prepare-time arenas, RAII for drivers, explicit error returns, and no allocations in pacing/interrupt paths. Disable exceptions/RTTI in embedded builds unless a selected dependency requires them. Host tests can use richer tooling without changing engine behavior.

Store geometry as calibrated sections with a physical-distance lookup, rather than copying all the Python per-pixel timing arrays. Clamp every rendered pixel to the actual strip length; define consistently whether the saved last-LED value is an inclusive index. Support explicit 25-yard, 25-metre, and 50-metre profiles. During the initial migration, reject unsupported partial-length plans clearly rather than silently rounding to a whole length; adding partial-length execution is a separately tested extension.

### UART contract

Use framed messages with protocol version, message type, boot/session ID, request ID, payload length, and CRC. COBS with a delimiter is a suitable framing choice. Serialize integers with a specified byte order; never transmit raw C++ structs. CRC detects transmission corruption, not authorization.

- Begin with 115200 baud to match the vendor reference; qualify a higher rate such as 921600 only after stress testing. [Vendor UART example](https://raw.githubusercontent.com/Xinyuan-LilyGO/Lilygo-T-Pico2/master/examples/ATDebug/ATDebug.ino).
- Bound frames to about 256 payload bytes initially, with bounded RX/TX buffers, timeouts, and flow control verified electrically. Do not enqueue an entire upload ahead of Stop.
- Transfer plans using BEGIN/CHUNK/COMMIT, a total-size bound, and an end-to-end checksum. Validate into a staging buffer and atomically replace the prepared plan only after successful validation. Reject preparation while running; an interrupted transfer leaves the previous plan intact.
- Include plan ID and pool/calibration revision in Prepare and Start. RP2350 validates both. ESP persistence owns the durable configuration; a prepared RP plan uses an immutable snapshot of it.
- Prioritize Stop and local controls over uploads and telemetry. Duplicate Start requests must return the recorded result, not restart a workout. Session IDs invalidate commands from before a reboot; rejected/queued/applied responses are distinct.
- Report status sequence, boot ID, applied request ID, fault, and snapshot age. The ESP must never present stale “running” telemetry as current. Time out HTTP waits without claiming a command succeeded; resolve uncertain outcomes by request ID/status.
- Wi-Fi loss alone does not stop an already accepted local workout. Proposed link-loss policy: three seconds without an ESP heartbeat causes RP2350 to stop outputs and require explicit recovery. Keep the heartbeat independent of browser presence. Confirm this policy before field deployment.
- Either processor reboot triggers a handshake and state reconciliation. RP2350 boots idle with outputs off. An ESP reboot does not replay queued Start commands. Physical local stop works without Wi-Fi or ESP cooperation.

12 KiB requires roughly 1.07 seconds on a 115200-baud 8N1 UART before framing/acknowledgments. This is acceptable for Prepare, but demonstrates why command transfer cannot drive per-pixel timing. A lost connection or slow upload must never extend a pacing deadline.

### ESP services and persistence

Use separate responsibilities for Wi-Fi events, HTTP handling, serial transport, and storage. The HTTP server's APIs are not inherently thread-safe; marshal responses/work appropriately instead of sharing request handles across unsynchronized tasks. Bound slow clients and concurrent requests so a blocked upload cannot starve control. [ESP-IDF server guidance](https://docs.espressif.com/projects/esp-idf/en/stable/esp32c6/api-reference/protocols/esp_http_server.html).

Serve the existing assets from generated compressed firmware resources. Use NVS for small configuration/secrets and a pinned LittleFS component for saved workouts and larger JSON. Pin dependency versions and inspect their build/flash-concurrency requirements. [ESP-IDF NVS](https://docs.espressif.com/projects/esp-idf/en/stable/esp32c6/api-reference/storage/nvs_flash.html), [LittleFS component](https://components.espressif.com/components/joltwallet/littlefs).

Import exported MicroPython JSON rather than interpreting its raw filesystem layout. Preserve names, set formats, source text, pool calibration, and inclusive last-LED semantics. Wi-Fi import must use a private provisioning channel and must not enter Git or logs. Validate in staging, write a checksummed generation, verify it, then activate it while retaining the previous valid generation. A mount failure must not automatically format user data. Configuration edits cannot mutate an active RP plan.

Keep the 12 KiB compiled-plan bound distinct from saved-source bounds: one saved DeckScript source can already be 16,384 characters, and `sets.json` can contain multiple sets. Choose and document collection/file/pool limits after inventorying deployed data. Reject oversized import before changing storage and retain an export/backup path.

Prepare an ESP partition budget from the actual 4 MB module and measured binary/assets sizes. Do not assume dual OTA slots, all saved data, and assets automatically fit. First release should support recoverable USB flashing of each chip and ship a manifest pairing firmware/protocol versions. ESP OTA can follow using ESP-IDF rollback support; RP2350 remote update requires its own recovery design. [ESP-IDF OTA](https://docs.espressif.com/projects/esp-idf/en/stable/esp32c6/api-reference/system/ota.html).

## Performance and resource gates

These are initial engineering targets, not measurements or existing product guarantees:

| Item | Initial budget or acceptance target |
| --- | --- |
| Internal pacing | Absolute monotonic deadlines; scheduler lateness at most 1 ms under qualified load; preserve planned start-to-start timing without accumulated software drift |
| Clock accuracy | Measure oscillator drift over at least one hour against a reference; separate clock error from scheduler lateness and establish a product tolerance |
| Stop | Outputs settle within 100 ms of RP command receipt or local button recognition; separately measure browser-to-output latency |
| LED refresh | Assuming 800 kbit/s, 24-bit pixels: 910 pixels take 27.3 ms plus reset/latch; target about 30 Hz, never promise per-pixel sub-millisecond visible updates |
| LED buffers | 2,730 bytes per packed RGB frame at 910 pixels; budget DMA-specific packing and double buffering separately |
| LCD | A full 222×480 RGB565 frame costs 213,120 bytes; use partial updates/tile buffers rather than allocating two full frames |
| Plan | At most 256 entries/12 KiB prepare JSON; account separately for decoded structs, UTF-8 labels, staging, and geometry |
| Telemetry | Initial 5 Hz snapshots with bounded/coalesced queues; retain the coach UI's current 2-second polling behavior |
| Memory | Map-file and stack/heap high-water reports for each build, no engine allocations while running, and explicit margin under worst-case plan/storage/network load |
| Recovery | Power loss, malformed frames, serial disconnect, and either MCU reboot must lead to documented states without an unintended restart |

At maximum strip length, compute the position for the intended display time and skip obsolete frames instead of delaying the workout to draw every intermediate LED. Measure DMA completion/latch effects and audio-to-light alignment with a logic analyzer. Do not mistake a fast engine tick for a faster serial LED bus.

## Delivery sequence

| Phase | Deliverables | Exit gate |
| --- | --- | --- |
| 0. Freeze behavior and hardware | Board/wiring manifest; exported device data; route/schema inventory; reference traces; defect/intentional-change ledger | Every workflow has expected behavior; pin/reset and LED/audio hardware questions resolved; known-good firmware/data backed up |
| 1. Establish native builds | Portable core skeleton; host CMake tests; Pico SDK RP2350 target; ESP-IDF C6 target; reproducible dependency pins and CI | Clean host/RP/ESP builds from a fresh checkout; USB logs and recovery proven on both chips |
| 2. Port deterministic core | Geometry, validation, pacing strategies, state machine, cursor and audio schedules | Golden/differential fixtures pass for supported legacy and DeckScript cases; deliberate corrections have explicit expected results |
| 3. Bring up RP peripherals | Board initialization, LCD, local stop, LED PIO/DMA, audio, watchdog | One local workout runs without ESP; bounds, stop latency, direction, markers, and waveform measurements pass |
| 4. Implement serial contract | Framing/parser, handshake, transactional prepare, acknowledgments, snapshots, reconnect | Corrupt/truncated/repeated/out-of-order frames, upload interruption, queue saturation, and either-MCU reset tests pass |
| 5. Port ESP application | Wi-Fi/AP setup, HTTP compatibility, existing web assets, storage/import, admin controls | Current browser can prepare/run/stop/save/reload all supported modes on hardware; negative API tests and power-loss persistence tests pass |
| 6. Native simulation and qualification | Native desktop adapter, viewer/status parity, sanitizers, automated end-to-end tests, field measurements | Extended continuous runs, maximum plans, repeated clients, Wi-Fi churn, flash writes, and restart tests meet budgets |
| 7. Cut over | Paired firmware release, migration/import guide, recovery images, installation instructions | Physical-pool acceptance, successful backup/restore and rollback drill, and no MicroPython runtime dependency on either device |

Dependencies: phase 0 precedes hardware decisions; phase 1 precedes native implementation; phase 2 precedes timing qualification; phases 3–5 converge before phase 6. Move one validated subsystem at a time while keeping the Python version usable as a reference. Do not delete it until phase 7 acceptance.

Suggested implementation layout:

```text
firmware/
  core/                 # Portable domain calculations and engine
  protocol/             # Explicit wire schema, codec, shared constants
  rp2350/               # Pico SDK project and verified board drivers
  esp32/                # ESP-IDF project, HTTP, Wi-Fi, storage
  host/                 # Desktop adapter and simulator executable
tests/
  fixtures/             # Plans, API examples, geometry and timing traces
  native/               # Engine/protocol tests with a fake clock
  integration/          # HTTP/serial scenarios and device harness
```

Use separate build directories/toolchains for host, ARM RP2350, and RISC-V ESP32-C6. Keep JS/HTML/CSS as shared source assets rather than duplicating them into each firmware tree. Add CLion CMake profiles for host and Pico SDK, and document the ESP-IDF environment/build workflow. Python may remain a development/test/SDK tool; the migration removes the MicroPython runtime from production hardware.

The first implementation slice should be the host-buildable `PoolGeometry` and pacing engine with fake-clock fixtures from the current three pools, followed by one RP2350 local workout. This resolves the highest-risk behavior before networking and storage are integrated.

## Verification completed for this review

- `python3 tools/test_workout_runner.py` — passed.
- `python3 tools/test_swimset_display.py` — passed.
- `node tools/test_deckscript.js` — passed.
- `python3 tools/smoke_emulator.py` — passed in an isolated temporary checkout so its configuration writes did not touch the working copy.

These checks cover existing host behavior, not native timing or electrical correctness. The runner tests use a fake SwimSet, the display test is small, and desktop clocks do not exercise MicroPython tick wrapping. Add geometry edges, invalid calibration, fractional values, stop at every transition, duplicate Start, continuous cycling, communication failures, and reset/power-loss cases to the migration fixtures. Use native address/undefined-behavior sanitizers and parser fuzzing where supported, plus logic-analyzer and real-device tests.

No physical device was accessed. No native firmware was built: `cmake`, `arm-none-eabi-g++`, and `idf.py` were not found on this session's PATH. Toolchain installation/configuration belongs to phase 1.

## Decisions still to confirm

1. Dual-chip LilyGO board versus independent standalone targets, and exact board revision.
2. Actual LED protocol/count/color order/pin/power interface and audio circuit.
3. Supported pool lengths/units, partial-length requirements, and intended calibration interpretation.
4. Preferred behavior after ESP/UART failure; the proposed default is stop after a three-second heartbeat timeout.
5. Whether local touch UI, SD, battery telemetry, or OTA is required for initial parity. The current application does not establish those as mandatory features.

If standalone ESP32 operation is also required, reuse the same portable engine locally, supply an ESP LED/output backend, and replace the UART engine client with an in-process command adapter. A standalone RP2350 target needs a specified network module or a USB/local-control-only product definition. These are additional qualification targets rather than assumptions hidden in the first migration.

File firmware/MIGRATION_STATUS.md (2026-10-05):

# C++ migration status

Last updated: 2026-09-25

- [x] Portable, fixed-capacity C++17 domain model, pool geometry, and workout
  state machine with nonblocking audio scheduling.
- [x] Shared COBS/CRC UART framing and transactional, checksummed plan buffer.
- [x] Native simulator, fake-clock coverage, protocol failure coverage, and
  AddressSanitizer/UndefinedBehaviorSanitizer host test configuration.
- [x] RP2350 Pico SDK project cross-compiles; its bounded UART0 command service
  handles session handshake, 1–256-rep pace sets, continuous sprint sets,
  Start, Stop, Cancel, and Status.
- [x] ESP32-C6 ESP-IDF project cross-compiles and forwards pace/sprint HTTP
  commands to the RP2350, returning 503 on transport failure.
- [x] Toolchain versions are pinned in `toolchains.lock`; host, RP2350, and
  ESP32-C6 use separate build directories.
- [x] Board profiles target the separate Waveshare RP2350B Plus W and
  ESP32-C6-LCD-1.9 connected on GP0/GP1 ↔ GPIO17/GPIO16.
- [x] Both C++ builds flashed to the separate boards; ESP boot-time UART
  status probe and RP request/response counters pass on 2026-09-25.
- [x] ESP32-C6 joins a provisioned Wi-Fi SSID, reports its DHCP address over
  USB, and renders connection/IP status through the onboard LCD driver. The
  `beaver` connection and HTTP `/` and `/api/set-status` returned successfully
  on 2026-09-25. The user confirmed the LCD displays the IP after correcting
  GPIO15's active-low backlight polarity.
- [x] Temporary AP-only firmware flashed on 2026-09-25. USB boot log confirms
  `Rabbit-Test-6905`, DHCP at `192.168.4.1`, and no station connection;
  Beaver credentials remain stored. The user confirmed the LCD shows
  `192.168.4.1` and the direct-AP webpage loads on the phone.
- [x] Station/AP test firmware now joins `beaver` from stored NVS credentials,
  displays its DHCP address on the LCD, and retains the Rabbit test AP as a
  fallback. On 2026-09-25 it received `192.168.0.178`; host requests returned
  HTTP 200 for the Coach On Deck page, assets, pool/sets data, and RP status.
- [x] Checked-in Coach On Deck HTML/CSS/JavaScript, pool list, and prompt are
  embedded in the ESP app. Saved sets are validated and stored in ESP NVS.
  Both updated boards are flashed; USB confirms the AP HTTP server and UART
  handshake. Phone browser verification of the new UI is pending.
- [x] Native debug and sanitizer tests pass for repeat, continuous,
  Stop/Continue, Cancel, and the expanded status frame.
- [x] DeckScript 2 compiled-plan JSON parsing, bounded CRC-checked UART plan
  transfer, and Pico swim/rest/activity execution are flashed on both boards.
  Native and sanitizer tests cover all checked-in DeckScript examples, surge,
  negative split, mixed steps, invalid input, and transfer sequencing. A live
  short surge/rest/swim workout completed through HTTP and UART, and a 30-step
  plan prepared through multi-chunk transfer on 2026-09-25. Phone-browser and
  pool-side acceptance remain pending.
- [x] RP2350 now supplies authoritative set details in its status frame. The
  ESP webpage retained `rep 3 of 20` and `200 yd` through an ESP restart during
  a running paired-device test on 2026-09-25. The LCD driver and polling task
  started without errors; physical confirmation of the new workout screen is
  still pending.
- [ ] Verify external LED and audio pin assignments on the RP2350 and visually
  confirm the LCD's workout phase, rep count, countdown, and IP display.
- [ ] Qualify the paired RP2350/ESP32 UART service, including real Stop
  latency, reboot reconciliation, and corrupted-frame recovery.
- [ ] Finish ESP Wi-Fi lifecycle, protected pool/Wi-Fi editing, calibrated
  LED geometry, and remaining full-plan edge-case acceptance. Unsupported
  plans/settings must continue to return explicit errors.
- [ ] Run paired-device, browser compatibility, timing, long-duration, power
  loss, recovery, and physical-pool acceptance tests.
- [ ] Remove the MicroPython production runtime only after the preceding
  hardware acceptance gates pass. The Python implementation remains the
  current reference and recovery path.

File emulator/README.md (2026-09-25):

# Rabbit Desktop Emulators

This adds a local emulator for the LED strand, pool-bottom tracing, OLED/TFT
display text, and the existing Rabbit web interface.

## Run

From repo root:

```bash
python3 emulator/run_desktop_emulator.py
```

Then open:
- Emulator view: `http://127.0.0.1:8080/emulator`
- Rabbit web UI: `http://127.0.0.1:8080`

## Notes

- Hardware-specific MicroPython modules are stubbed from `emulator/stubs/`.
- Absolute runtime paths like `/db/pools.json` are redirected to `./db/pools.json`.
- `main.py` still runs as-is; the launcher only patches runtime behavior for desktop emulation.

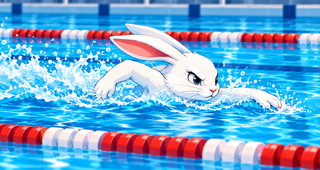
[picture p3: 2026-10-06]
static/swimming_rabbit_320x170.png

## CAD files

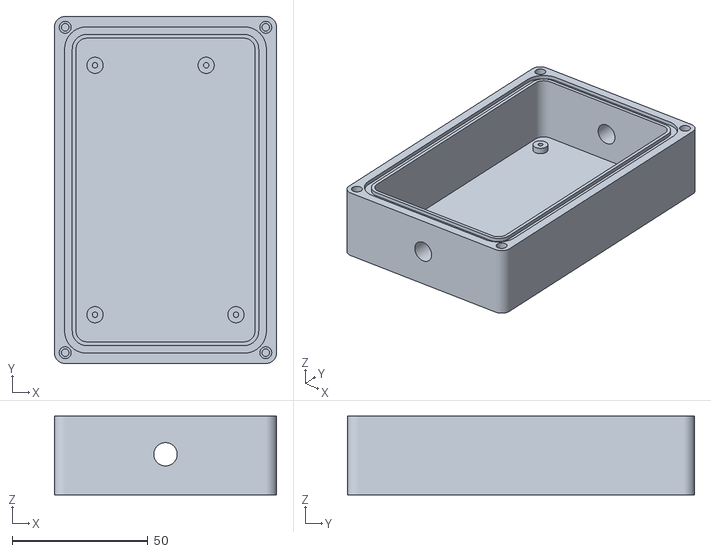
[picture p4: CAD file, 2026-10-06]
mechanical/resin_housing/stl/body_petg.stl
82.0 x 128.0 x 29.1

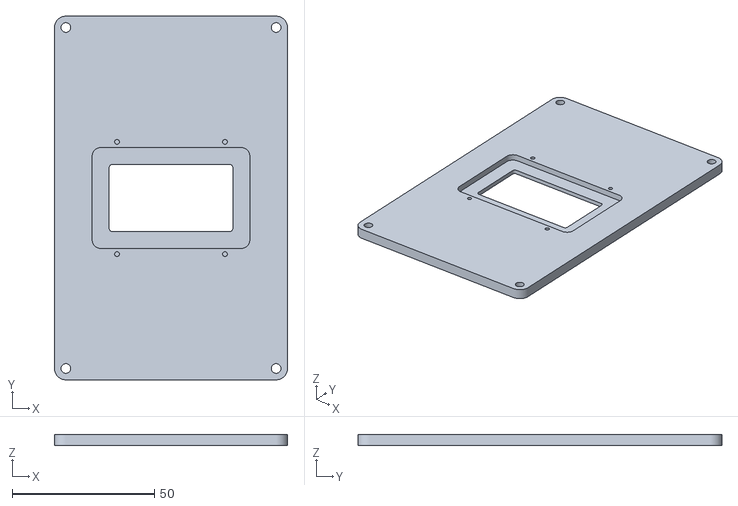
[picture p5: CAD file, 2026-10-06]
mechanical/resin_housing/stl/lid_frame_petg.stl
82.0 x 128.0 x 4.00

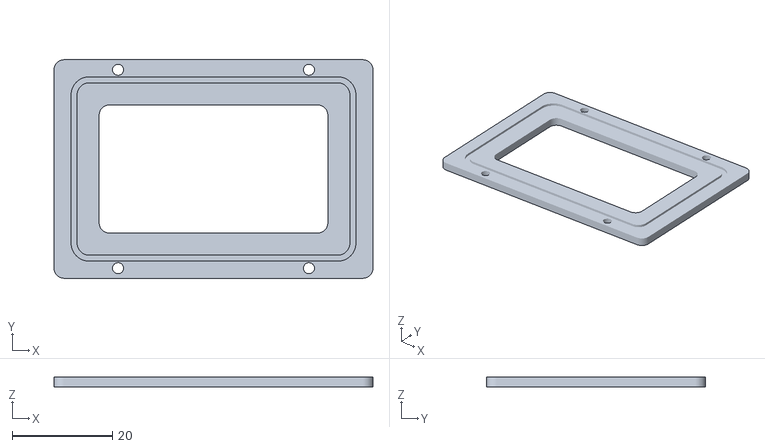
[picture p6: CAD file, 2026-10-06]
mechanical/resin_housing/stl/window_retainer_petg.stl
63.5 x 43.5 x 2.00

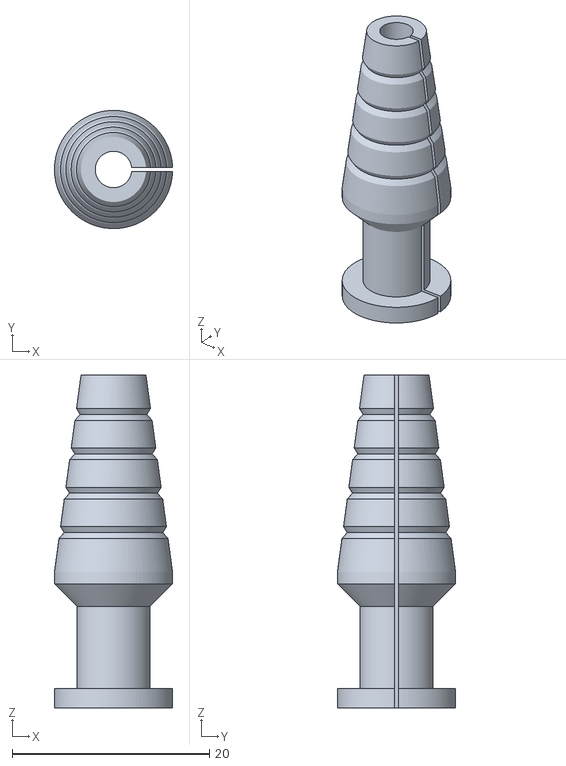
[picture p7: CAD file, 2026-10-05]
mechanical/resin_housing/stl/strain_relief_3_5mm_split_wrap_tpu.stl
12.0 x 12.0 x 33.8

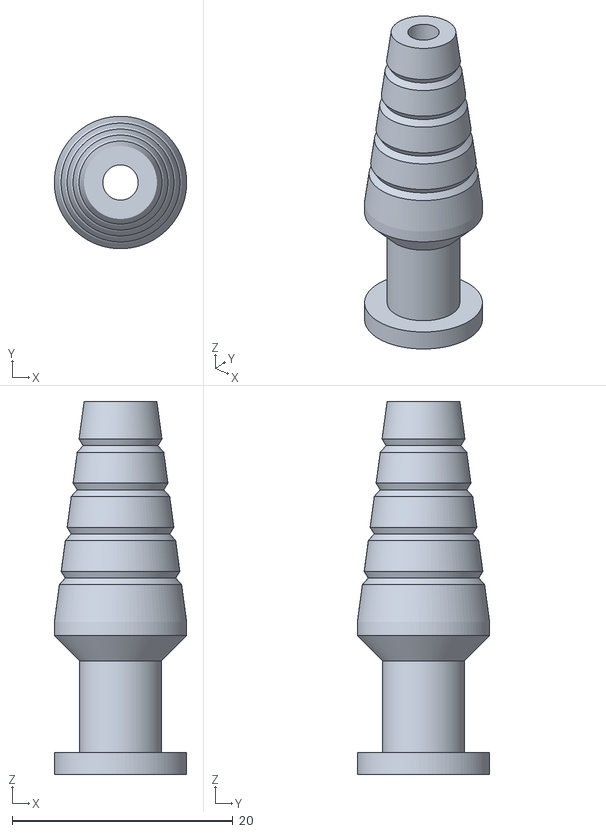
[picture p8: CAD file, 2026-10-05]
mechanical/resin_housing/stl/strain_relief_3_0mm_closed_tpu.stl
12.0 x 12.0 x 33.8

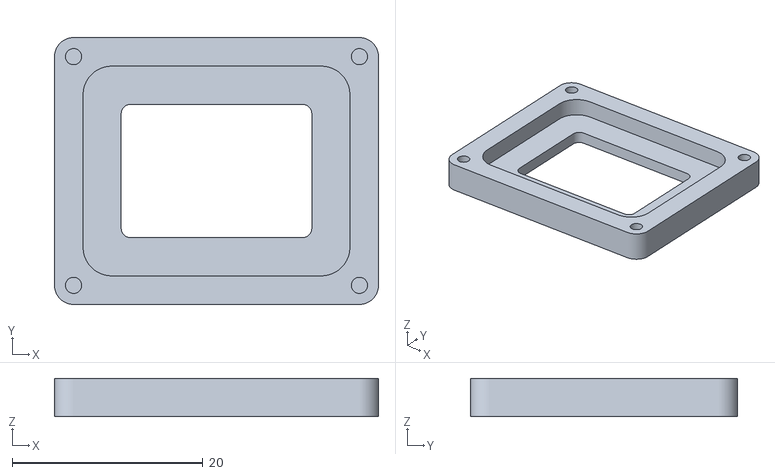
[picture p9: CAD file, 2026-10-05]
mechanical/resin_housing/stl/resin_cast_fit_coupon_petg.stl
34.0 x 28.0 x 4.00

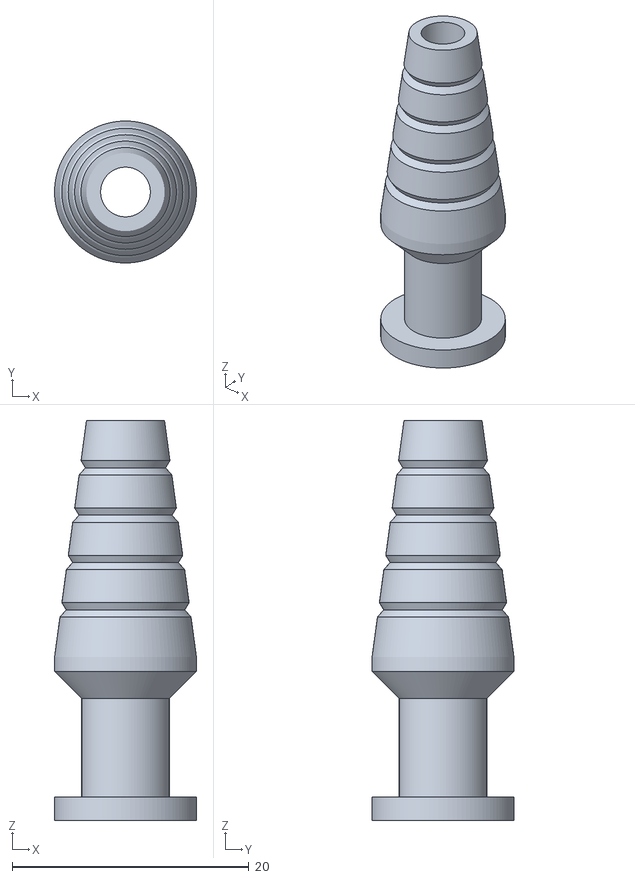
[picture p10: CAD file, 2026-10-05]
mechanical/resin_housing/stl/strain_relief_4_0mm_closed_tpu.stl
12.0 x 12.0 x 33.8

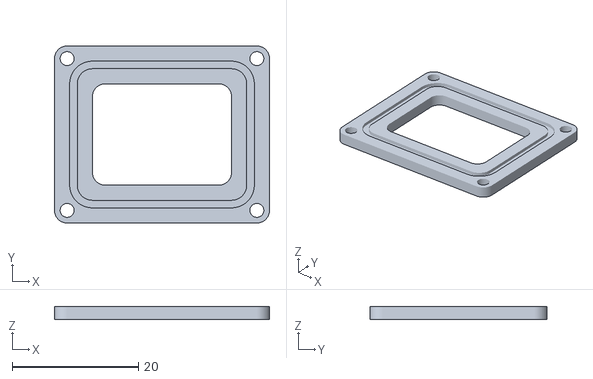
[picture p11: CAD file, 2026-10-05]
mechanical/resin_housing/stl/resin_coupon_retainer_petg.stl
34.0 x 28.0 x 2.00

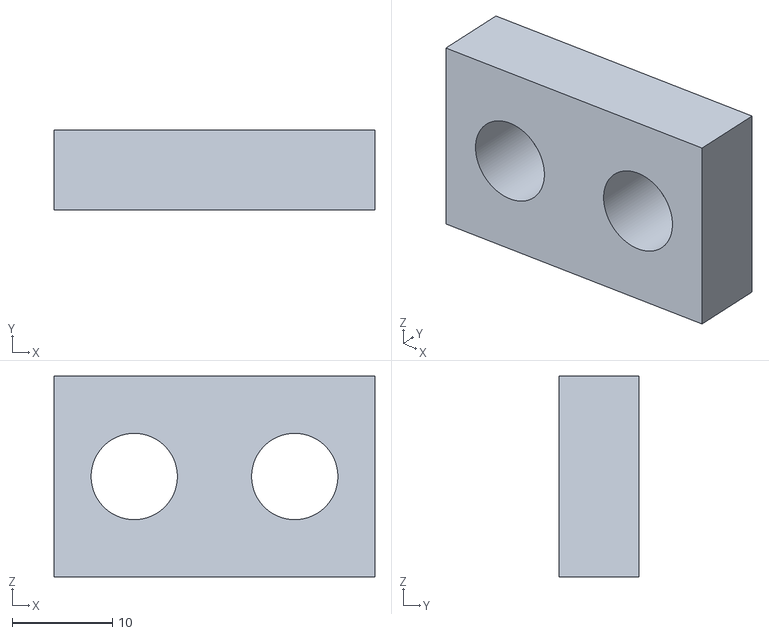
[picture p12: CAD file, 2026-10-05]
mechanical/resin_housing/stl/cable_entry_fit_coupon_petg.stl
32.0 x 8.00 x 20.0

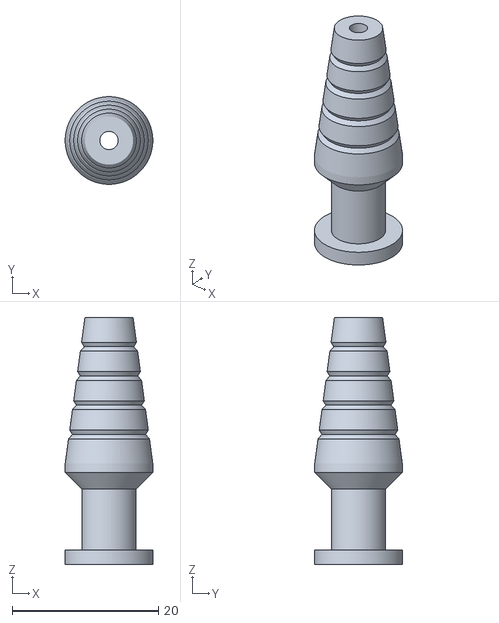
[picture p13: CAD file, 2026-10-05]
mechanical/resin_housing/stl/strain_relief_2_3mm_closed_tpu.stl
12.0 x 12.0 x 33.8

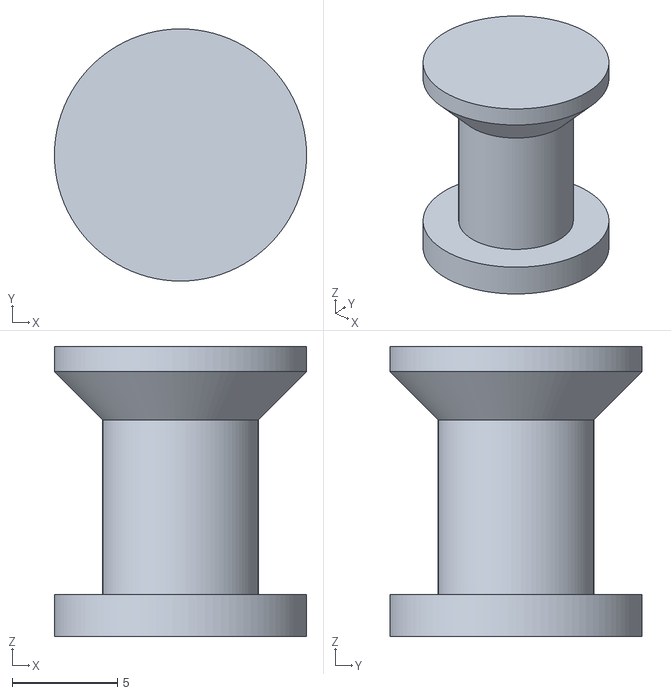
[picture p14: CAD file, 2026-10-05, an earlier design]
mechanical/resin_housing/stl/unused_entry_plug_tpu.stl
12.0 x 12.0 x 13.8

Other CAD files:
mechanical/resin_housing/stl/strain_relief_4_0mm_split_wrap_tpu.stl
mechanical/resin_housing/stl/strain_relief_3_0mm_split_wrap_tpu.stl
mechanical/resin_housing/stl/strain_relief_3_5mm_closed_tpu.stl
mechanical/resin_housing/stl/strain_relief_2_3mm_split_wrap_tpu.stl

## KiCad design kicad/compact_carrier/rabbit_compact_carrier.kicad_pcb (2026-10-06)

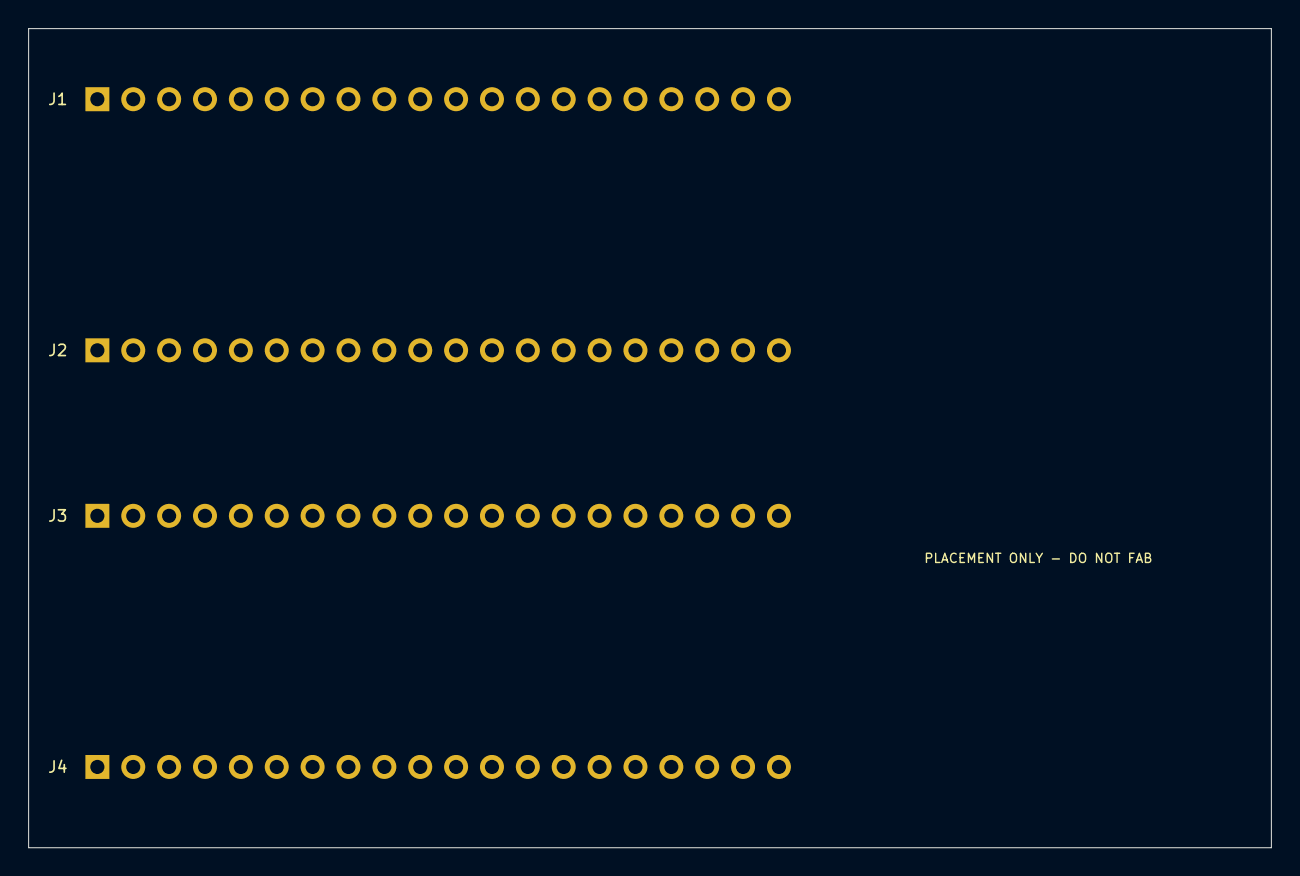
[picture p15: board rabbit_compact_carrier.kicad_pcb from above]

Board: 2 copper layers, 88.0 x 58.0 mm, 4 parts (0 on the bottom side), 3 nets, no tracks yet.

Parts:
J1: ESP_IO16_IO17_ROW; Socket_1x20_Horizontal
J2: ESP_OPPOSITE_ROW; Socket_1x20_Horizontal
J3: RP_GP0_GP1_ROW; Socket_1x20_Horizontal
J4: RP_OPPOSITE_ROW; Socket_1x20_Horizontal

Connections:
ESP_IO16_TO_RP_GP1: J1.1, J3.2
GND: J1.3, J3.3
RP_GP0_TO_ESP_IO17: J1.2, J3.1

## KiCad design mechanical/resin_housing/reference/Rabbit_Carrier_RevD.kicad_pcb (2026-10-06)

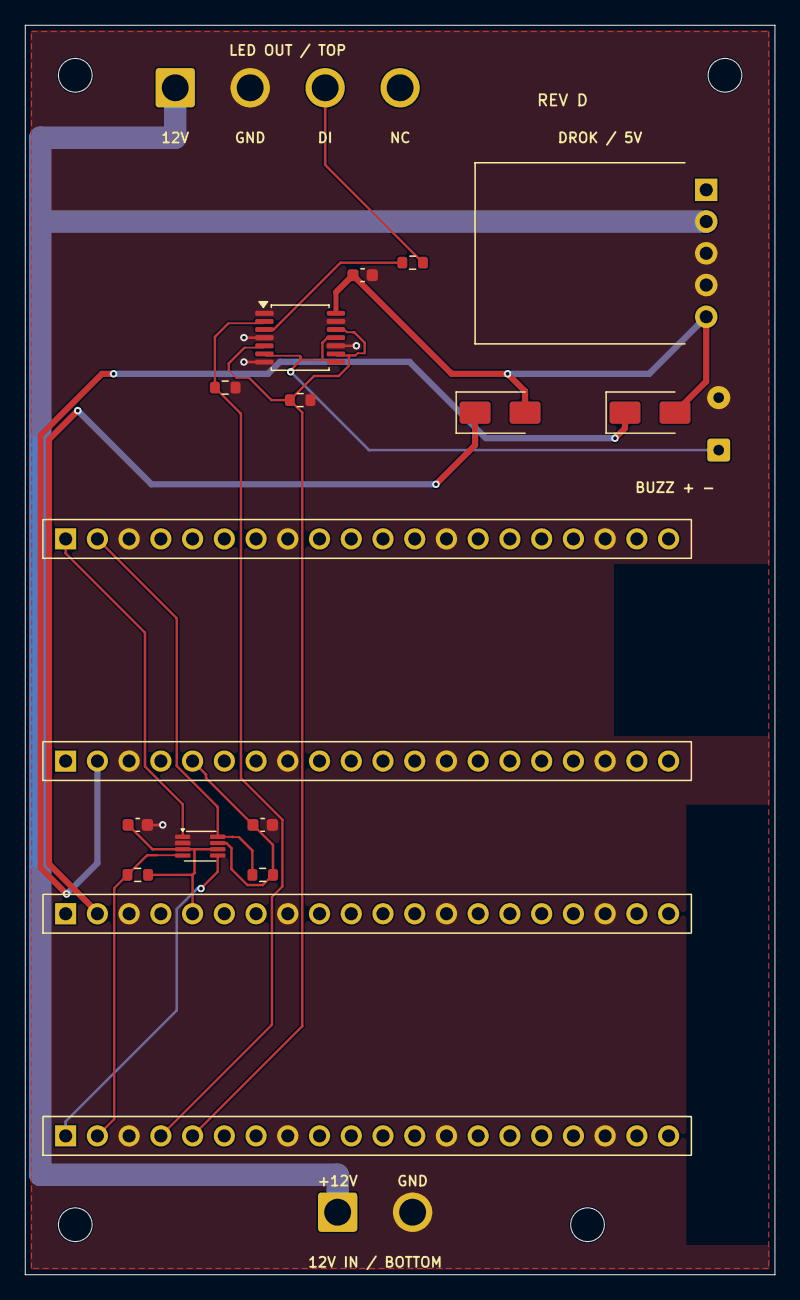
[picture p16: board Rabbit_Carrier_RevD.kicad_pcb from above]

Board: 2 copper layers, 60.0 x 100.0 mm, 24 parts (0 on the bottom side), 16 nets.

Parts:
C4, C5, C8: 100n_25V_X7R; C_0603_1608Metric
D2: SS24_RP_VSYS; D_SMA
D3: SS24_ESP_VSYS; D_SMA
H1, H2, H3, H4: M2.5_NPTH; MountingHole_2.7mm_M2.5
J1: RP_L_20P; Bossie_BX-PM2.54-1-20PY
J2: RP_R_20P; Bossie_BX-PM2.54-1-20PY
J3: ESP_L_20P; Bossie_BX-PM2.54-1-20PY
J4: ESP_R_20P; Bossie_BX-PM2.54-1-20PY
J5: 12V_INPUT_HARDWIRE; SolderWire-1.5sqmm_1x02_P6mm_D1.7mm_OD3mm
J6: LED_STRIP_HARDWIRE; SolderWire-1.5sqmm_1x04_P6mm_D1.7mm_OD3mm
J9: BUZZER_DIRECT_AHCT; SolderWire-0.25sqmm_1x02_P4.2mm_D0.65mm_OD1.7mm
MOD1: DROK_12V_TO_5V_PROVISIONAL; DROK_200548_5pad_PROVISIONAL
R3, R4, R5, R10: 10k; R_0603_1608Metric
R6: 330; R_0603_1608Metric
U2: TXU0202_UART_ISOLATOR; TXU0202_DCU_RowMask
U4: SN74AHCT125PW; TSSOP-14_4.4x5mm_P0.65mm

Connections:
12V_IN: J5.1, J6.1, MOD1.2
BUZZ_BUF: J9.1, U4.6, U4.8, U4.11
DROK_5V: C8.1, D2.2, D3.2, MOD1.5, U4.14
ESP_3V3: C5.1, J4.5, R4.2, U2.7
ESP_RX: J3.2, R4.1, U2.8
ESP_TX: J3.1, U2.1
ESP_VSYS: D3.1, J4.2
GND: C4.2, C5.2, C8.2, J1.3, J1.8, J1.13, J1.18, J2.3, J2.8, J2.13, J2.18, J3.3, J3.8, J3.13, J3.18, J4.3, J4.8, J4.13, J4.18, J5.2, J6.2, J9.2, MOD1.3, MOD1.4, R5.2, R10.2, U2.2, U4.1, U4.4, U4.7, U4.10, U4.13
LED_BUF: R6.1, U4.3
LED_DI: J6.3, R6.2
RP_3V3: C4.1, J2.5, R3.2, U2.3, U2.6
RP_BUZZ: J1.5, R10.1, U4.5, U4.9, U4.12
RP_LED: J1.4, R5.1, U4.2
RP_RX: J1.2, R3.1, U2.4
RP_TX: J1.1, U2.5
RP_VSYS: D2.1, J2.2

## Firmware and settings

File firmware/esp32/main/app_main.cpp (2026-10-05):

#include <cinttypes>
#include <algorithm>
#include <array>
#include <cmath>
#include <cstdio>
#include <cstdlib>
#include <cstring>
#include <memory>

extern "C" {
#include "driver/uart.h"
#include "cJSON.h"
#include "esp_event.h"
#include "esp_http_server.h"
#include "esp_mac.h"
#include "esp_netif.h"
#include "esp_random.h"
#include "esp_timer.h"
#include "esp_wifi.h"
#include "freertos/FreeRTOS.h"
#include "freertos/semphr.h"
#include "freertos/task.h"
#include "nvs.h"
#include "nvs_flash.h"
}

#include "rabbit/protocol/framing.hpp"
#include "rabbit/protocol/plan_codec.hpp"
#include "rabbit/protocol/workout_service.hpp"
#include "deckscript_bridge.hpp"
#include "lcd_status.hpp"
#include "web_ui.hpp"
#include "audio_api.hpp"
#include "wifi_provision.hpp"

namespace {
constexpr uart_port_t kUart = UART_NUM_0;
constexpr int kUartTxPin = 16;
constexpr int kUartRxPin = 17;
constexpr int kUartRtsPin = UART_PIN_NO_CHANGE;
constexpr int kUartCtsPin = UART_PIN_NO_CHANGE;
constexpr int kHttpBodyLimit = 256;
constexpr int kMaxPlanBodyBytes = 12 * 1024;
constexpr std::int64_t kResponseTimeoutUs = 1'500'000;
// Keep the direct-connect AP as a fallback while testing the provisioned station.
constexpr bool kTestApOnly = false;
constexpr char kTestAccessPointPassword[] = "rabbit-test-2026";
constexpr char kTestAccessPointAddress[] = "192.168.4.1";
wifi_config_t wifi_configuration{};
char test_access_point_ssid[33]{};
bool wifi_scan_active = false;
bool wifi_scan_completed = false;
bool wifi_station_configured = false;

void configure_test_access_point() {
    std::uint8_t mac[6]{};
    ESP_ERROR_CHECK(esp_read_mac(mac, ESP_MAC_WIFI_SOFTAP));
    const int ssid_length = std::snprintf(
        test_access_point_ssid, sizeof(test_access_point_ssid), "Rabbit-Test-%02X%02X",
        static_cast<unsigned int>(mac[4]), static_cast<unsigned int>(mac[5]));
    if (ssid_length <= 0 || static_cast<std::size_t>(ssid_length) >= sizeof(test_access_point_ssid)) std::abort();

    wifi_config_t access_point{};
    std::memcpy(access_point.ap.ssid, test_access_point_ssid, static_cast<std::size_t>(ssid_length));
    std::memcpy(access_point.ap.password, kTestAccessPointPassword, sizeof(kTestAccessPointPassword) - 1U);
    access_point.ap.ssid_len = static_cast<std::uint8_t>(ssid_length);
    access_point.ap.channel = 1;
    access_point.ap.max_connection = 1;
    access_point.ap.authmode = WIFI_AUTH_WPA2_PSK;
    ESP_ERROR_CHECK(esp_wifi_set_config(WIFI_IF_AP, &access_point));
    std::printf("Rabbit test AP ready: SSID=%s address=%s\n", test_access_point_ssid,
                kTestAccessPointAddress);
}

bool load_wifi_credentials(wifi_config_t& configuration) {
    nvs_handle_t storage{};
    if (nvs_open("rabbit_net", NVS_READONLY, &storage) != ESP_OK) return false;
    std::size_t ssid_size = sizeof(configuration.sta.ssid);
    std::size_t password_size = sizeof(configuration.sta.password);
    const auto ssid_result = nvs_get_str(storage, "ssid", reinterpret_cast<char*>(configuration.sta.ssid), &ssid_size);
    const auto password_result = nvs_get_str(storage, "password", reinterpret_cast<char*>(configuration.sta.password), &password_size);
    nvs_close(storage);
    return ssid_result == ESP_OK && password_result == ESP_OK;
}

void scan_configured_network() {
    if (wifi_scan_active) return;
    wifi_scan_config_t scan{};
    scan.show_hidden = true;
    if (esp_wifi_scan_start(&scan, false) == ESP_OK) wifi_scan_active = true;
}

void report_configured_network() {
    std::array<wifi_ap_record_t, 16> records{};
    std::uint16_t count = static_cast<std::uint16_t>(records.size());
    if (esp_wifi_scan_get_ap_records(&count, records.data()) != ESP_OK) {
        std::puts("Rabbit Wi-Fi scan failed");
        return;
    }
    for (std::uint16_t index = 0; index < count; ++index) {
        if (std::strcmp(reinterpret_cast<const char*>(records[index].ssid),
                        reinterpret_cast<const char*>(wifi_configuration.sta.ssid)) == 0) {
            std::printf("Rabbit Wi-Fi SSID visible: channel=%u rssi=%d\n",
                        static_cast<unsigned int>(records[index].primary), static_cast<int>(records[index].rssi));
            return;
        }
    }
    std::puts("Rabbit Wi-Fi SSID not visible in C6 scan");
}

void wifi_event_handler(void*, const esp_event_base_t event_base, const std::int32_t event_id, void* event_data) {
    if (event_base == WIFI_EVENT && event_id == WIFI_EVENT_AP_STACONNECTED) {
        const auto* event = static_cast<const wifi_event_ap_staconnected_t*>(event_data);
        std::printf("Rabbit test AP client connected: aid=%u\n", static_cast<unsigned int>(event->aid));
    } else if (event_base == WIFI_EVENT && event_id == WIFI_EVENT_AP_STADISCONNECTED) {
        const auto* event = static_cast<const wifi_event_ap_stadisconnected_t*>(event_data);
        std::printf("Rabbit test AP client disconnected: aid=%u\n", static_cast<unsigned int>(event->aid));
    } else if (event_base == WIFI_EVENT && event_id == WIFI_EVENT_STA_START) {
        if (!wifi_station_configured) return;
        const auto result = esp_wifi_connect();
        if (result != ESP_OK && result != ESP_ERR_WIFI_CONN) {
            std::printf("Rabbit Wi-Fi connect request failed: %ld\n", static_cast<long>(result));
        }
    } else if (event_base == WIFI_EVENT && event_id == WIFI_EVENT_STA_DISCONNECTED) {
        if (!wifi_station_configured) return;
        const auto* event = static_cast<const wifi_event_sta_disconnected_t*>(event_data);
        std::printf("Rabbit Wi-Fi disconnected: reason=%u\n", static_cast<unsigned int>(event->reason));
        rabbit::esp32::show_lcd_status("RECONNECTING", kTestAccessPointAddress);
        if (event->reason == WIFI_REASON_NO_AP_FOUND && !wifi_scan_completed) {
            wifi_scan_completed = true;
            scan_configured_network();
            return;
        }
        const auto result = esp_wifi_connect();
        if (result != ESP_OK && result != ESP_ERR_WIFI_CONN) {
            std::printf("Rabbit Wi-Fi reconnect failed: %ld\n", static_cast<long>(result));
        }
    } else if (event_base == IP_EVENT && event_id == IP_EVENT_STA_GOT_IP) {
        const auto* event = static_cast<const ip_event_got_ip_t*>(event_data);
        std::printf("Rabbit Wi-Fi connected: " IPSTR "\n", IP2STR(&event->ip_info.ip));
        char address[16]{};
        std::snprintf(address, sizeof(address), IPSTR, IP2STR(&event->ip_info.ip));
        rabbit::esp32::show_lcd_status("BEAVER", address);
    } else if (event_base == WIFI_EVENT && event_id == WIFI_EVENT_SCAN_DONE) {
        wifi_scan_active = false;
        report_configured_network();
        static_cast<void>(esp_wifi_connect());
    }
}

void start_wifi() {
    auto* const ap_netif = esp_netif_create_default_wifi_ap();
    if (ap_netif == nullptr || (!kTestApOnly && esp_netif_create_default_wifi_sta() == nullptr)) {
        std::puts("Rabbit Wi-Fi network interfaces could not be created");
        return;
    }
    const wifi_init_config_t init = WIFI_INIT_CONFIG_DEFAULT();
    ESP_ERROR_CHECK(esp_wifi_init(&init));
    if (!kTestApOnly) {
        // The browser is interactive; avoid DTIM-delayed packets on the STA link.
        ESP_ERROR_CHECK(esp_wifi_set_ps(WIFI_PS_NONE));
    }
    ESP_ERROR_CHECK(esp_event_handler_register(WIFI_EVENT, ESP_EVENT_ANY_ID, &wifi_event_handler, nullptr));
    ESP_ERROR_CHECK(esp_event_handler_register(IP_EVENT, IP_EVENT_STA_GOT_IP, &wifi_event_handler, nullptr));
    ESP_ERROR_CHECK(esp_wifi_set_mode(kTestApOnly ? WIFI_MODE_AP : WIFI_MODE_APSTA));
    configure_test_access_point();
    if (!kTestApOnly) {
        wifi_station_configured = load_wifi_credentials(wifi_configuration);
        if (wifi_station_configured) {
            std::printf("Rabbit Wi-Fi credentials loaded for SSID=%s\n", wifi_configuration.sta.ssid);
            rabbit::esp32::show_lcd_status("CONNECTING", kTestAccessPointAddress);
            ESP_ERROR_CHECK(esp_wifi_set_config(WIFI_IF_STA, &wifi_configuration));
        } else {
            rabbit::esp32::show_lcd_status("SETUP WIFI", kTestAccessPointAddress);
            std::puts("Rabbit Wi-Fi credentials are not provisioned; use the local test AP");
        }
    }
    ESP_ERROR_CHECK(esp_wifi_start());
    if (kTestApOnly) {
        esp_netif_ip_info_t ip_info{};
        ESP_ERROR_CHECK(esp_netif_get_ip_info(ap_netif, &ip_info));
        char address[16]{};
        std::snprintf(address, sizeof(address), IPSTR, IP2STR(&ip_info.ip));
        rabbit::esp32::show_lcd_status("RABBIT AP", address);
        std::printf("Rabbit AP-only test mode: http://%s/; saved Wi-Fi credentials unchanged\n", address);
    }
    if (wifi_station_configured) std::puts("Rabbit Wi-Fi connecting");
}

void write_u32(std::uint8_t* bytes, const std::uint32_t value) {
    bytes[0] = static_cast<std::uint8_t>(value >> 24U);
    bytes[1] = static_cast<std::uint8_t>(value >> 16U);
    bytes[2] = static_cast<std::uint8_t>(value >> 8U);
    bytes[3] = static_cast<std::uint8_t>(value);
}

void write_u16(std::uint8_t* bytes, const std::uint16_t value) {
    bytes[0] = static_cast<std::uint8_t>(value >> 8U);
    bytes[1] = static_cast<std::uint8_t>(value);
}

std::uint16_t read_u16(const std::uint8_t* bytes) {
    return static_cast<std::uint16_t>((static_cast<std::uint16_t>(bytes[0]) << 8U) | bytes[1]);
}

std::uint32_t read_u32(const std::uint8_t* bytes) {
    return (static_cast<std::uint32_t>(bytes[0]) << 24U) |
        (static_cast<std::uint32_t>(bytes[1]) << 16U) |
        (static_cast<std::uint32_t>(bytes[2]) << 8U) |
        static_cast<std::uint32_t>(bytes[3]);
}

class UartClient {
public:
    void initialise() {
        mutex_ = xSemaphoreCreateMutex();
        if (mutex_ == nullptr) std::abort();
        uart_config_t config{};
        config.baud_rate = 115200;
        config.data_bits = UART_DATA_8_BITS;
        config.parity = UART_PARITY_DISABLE;
        config.stop_bits = UART_STOP_BITS_1;
        config.flow_ctrl = UART_HW_FLOWCTRL_DISABLE;
        config.rx_flow_ctrl_thresh = 64;
        config.source_clk = UART_SCLK_DEFAULT;
        ESP_ERROR_CHECK(uart_driver_install(kUart, 1024, 1024, 0, nullptr, 0));
        ESP_ERROR_CHECK(uart_param_config(kUart, &config));
        ESP_ERROR_CHECK(uart_set_pin(kUart, kUartTxPin, kUartRxPin, kUartRtsPin, kUartCtsPin));
        session_id_ = esp_random() | 1U;
    }

    [[nodiscard]] bool prepare(const std::uint32_t distance_mm, const std::uint32_t target_ms,
                               const std::uint32_t interval_ms, const std::uint8_t flags,
                               const std::uint16_t repetitions = 1, const std::uint32_t final_target_ms = 0,
                               const std::uint16_t surge_permille = 0) {
        std::uint8_t payload[rabbit::protocol::kPrepareSetPayloadSize]{};
        payload[0] = flags;
        write_u32(payload + 1, distance_mm);
        write_u32(payload + 5, target_ms);
        write_u32(payload + 9, interval_ms);
        write_u16(payload + 13, repetitions);
        write_u32(payload + 15, final_target_ms == 0 ? target_ms : final_target_ms);
        write_u16(payload + 19, surge_permille);
        rabbit::protocol::Frame response{};
        return call(rabbit::protocol::MessageType::PrepareBegin, payload, sizeof(payload), response);
    }

    [[nodiscard]] bool prepare_plan(const std::uint8_t* data, const std::uint16_t size) {
        if (data == nullptr || size == 0U || size > rabbit::protocol::kMaxPlanBytes) return false;
        const auto transfer_id = esp_random() | 1U;
        std::uint8_t begin[10]{};
        write_u32(begin, transfer_id);
        write_u16(begin + 4, size);
        write_u32(begin + 6, rabbit::protocol::crc32(data, size));
        rabbit::protocol::Frame response{};
        if (!call(rabbit::protocol::MessageType::PrepareBegin, begin, sizeof(begin), response)) return false;
        for (std::uint16_t offset = 0; offset < size;) {
            std::uint8_t chunk[246]{};
            const auto count = static_cast<std::uint16_t>(std::min<std::uint16_t>(240U, size - offset));
            write_u32(chunk, transfer_id);
            write_u16(chunk + 4, offset);
            std::memcpy(chunk + 6, data + offset, count);
            if (!call(rabbit::protocol::MessageType::PrepareChunk, chunk,
                      static_cast<std::uint16_t>(count + 6U), response)) return false;
            offset = static_cast<std::uint16_t>(offset + count);
        }
        std::uint8_t commit[4]{};
        write_u32(commit, transfer_id);
        return call(rabbit::protocol::MessageType::PrepareCommit, commit, sizeof(commit), response);
    }

    [[nodiscard]] bool start() {
        rabbit::protocol::Frame response{};
        return call(rabbit::protocol::MessageType::Start, nullptr, 0, response);
    }

    [[nodiscard]] bool stop() {
        rabbit::protocol::Frame response{};
        return call(rabbit::protocol::MessageType::Stop, nullptr, 0, response);
    }

    [[nodiscard]] bool cancel() {
        rabbit::protocol::Frame response{};
        return call(rabbit::protocol::MessageType::Cancel, nullptr, 0, response);
    }

    [[nodiscard]] bool status(rabbit::protocol::Frame& response) {
        return call(rabbit::protocol::MessageType::Status, nullptr, 0, response);
    }

    [[nodiscard]] bool audio(rabbit::protocol::MessageType type, const std::uint8_t* payload,
                             std::uint16_t size, rabbit::protocol::Frame& response) {
        return call(type, payload, size, response);
    }

private:
    [[nodiscard]] bool call(const rabbit::protocol::MessageType type, const std::uint8_t* payload,
                            const std::uint16_t payload_size, rabbit::protocol::Frame& response) {
        xSemaphoreTake(mutex_, portMAX_DELAY);
        const bool result = call_locked(type, payload, payload_size, response);
        xSemaphoreGive(mutex_);
        return result;
    }

    [[nodiscard]] bool call_locked(const rabbit::protocol::MessageType type, const std::uint8_t* payload,
                                   const std::uint16_t payload_size, rabbit::protocol::Frame& response) {
        const auto request_id = ++request_id_;
        for (int attempt = 0; attempt < 2; ++attempt) {
            if (!session_ready_ && !hello()) continue;
            rabbit::protocol::Frame request{};
            request.type = type;
            request.session_id = session_id_;
            request.request_id = request_id;
            request.payload_size = payload_size;
            if (payload_size != 0U) std::memcpy(request.payload.data(), payload, payload_size);
            if (!send(request) || !receive(request_id, response)) {
                session_ready_ = false;
                continue;
            }
            if (response.type == rabbit::protocol::MessageType::Reject) {
                if (response.payload_size >= 2U &&
                    response.payload[1] == static_cast<std::uint8_t>(rabbit::protocol::ServiceError::Session)) {
                    session_ready_ = false;
                    continue;
                }
                return false;
            }
            if (rabbit::protocol::is_audio_request(type)) return response.type ==
                ((type == rabbit::protocol::MessageType::AudioDevices || type == rabbit::protocol::MessageType::AudioSaved) ? type : rabbit::protocol::MessageType::AudioStatus);
            return type == rabbit::protocol::MessageType::Status ? response.type == rabbit::protocol::MessageType::Status :
                response.type == rabbit::protocol::MessageType::Ack;
        }
        return false;
    }

    [[nodiscard]] bool hello() {
        rabbit::protocol::Frame request{};
        rabbit::protocol::Frame response{};
        request.type = rabbit::protocol::MessageType::Hello;
        request.session_id = session_id_;
        request.request_id = ++request_id_;
        if (!send(request) || !receive(request.request_id, response) || response.type != rabbit::protocol::MessageType::Ack) {
            return false;
        }
        session_ready_ = true;
        return true;
    }

    [[nodiscard]] bool send(const rabbit::protocol::Frame& request) {
        rabbit::protocol::EncodedFrame encoded{};
        if (!rabbit::protocol::encode(request, encoded)) return false;
        const int written = uart_write_bytes(kUart, reinterpret_cast<const char*>(encoded.bytes.data()), encoded.size);
        const bool transmitted = written == static_cast<int>(encoded.size) &&
            uart_wait_tx_done(kUart, pdMS_TO_TICKS(100)) == ESP_OK;
        std::printf("Rabbit UART tx type=%u bytes=%u written=%d complete=%s\n",
                    static_cast<unsigned int>(request.type), static_cast<unsigned int>(encoded.size), written,
                    transmitted ? "yes" : "no");
        return transmitted;
    }

    [[nodiscard]] bool receive(const std::uint32_t expected_request_id, rabbit::protocol::Frame& response) {
        const auto deadline = esp_timer_get_time() + kResponseTimeoutUs;
        while (esp_timer_get_time() < deadline) {
            std::uint8_t bytes[64]{};
            const int count = uart_read_bytes(kUart, bytes, sizeof(bytes), pdMS_TO_TICKS(20));
            for (int index = 0; index < count; ++index) {
                rabbit::protocol::Frame decoded{};
                rabbit::protocol::DecodeError error{};
                if (decoder_.push(bytes[index], decoded, error) && decoded.session_id == session_id_ &&
                    decoded.request_id == expected_request_id) {
                    response = decoded;
                    return true;
                }
            }
        }
        return false;
    }

    rabbit::protocol::FrameDecoder decoder_{};
    std::uint32_t session_id_{1};
    std::uint32_t request_id_{0};
    bool session_ready_{false};
    SemaphoreHandle_t mutex_{nullptr};
};

UartClient transport{};

const char* value_for(const char* body, const char* key) {
    char quoted_key[48]{};
    const int written = std::snprintf(quoted_key, sizeof(quoted_key), "\"%s\"", key);
    if (written < 0 || static_cast<std::size_t>(written) >= sizeof(quoted_key)) return nullptr;
    const char* value = std::strstr(body, quoted_key);
    if (value == nullptr) return nullptr;
    value = std::strchr(value + written, ':');
    return value == nullptr ? nullptr : value + 1;
}

bool json_u32(const char* body, const char* key, const std::uint32_t fallback, std::uint32_t& result) {
    const char* value = value_for(body, key);
    if (value == nullptr) {
        result = fallback;
        return true;
    }
    char* end = nullptr;
    const unsigned long parsed = std::strtoul(value, &end, 10);
    if (end == value || parsed > UINT32_MAX) return false;
    result = static_cast<std::uint32_t>(parsed);
    return true;
}

bool json_true(const char* body, const char* key) {
    const char* value = value_for(body, key);
    return value != nullptr && std::strncmp(value, "true", 4) == 0;
}

int hex_digit(const char value) {
    if (value >= '0' && value <= '9') return value - '0';
    if (value >= 'a' && value <= 'f') return value - 'a' + 10;
    if (value >= 'A' && value <= 'F') return value - 'A' + 10;
    return -1;
}

bool query_value(const char* query, const char* key, char* output, const std::size_t capacity) {
    if (httpd_query_key_value(query, key, output, capacity) != ESP_OK) return false;
    std::size_t read = 0;
    std::size_t write = 0;
    while (output[read] != '\0') {
        if (output[read] == '%' && output[read + 1] != '\0' && output[read + 2] != '\0') {
            const int high = hex_digit(output[read + 1]);
            const int low = hex_digit(output[read + 2]);
            if (high < 0 || low < 0) return false;
            output[write++] = static_cast<char>((high << 4) | low);
            read += 3;
        } else {
            output[write++] = output[read] == '+' ? ' ' : output[read];
            ++read;
        }
    }
    output[write] = '\0';
    return true;
}

bool parse_positive_u32(const char* text, std::uint32_t& output) {
    if (text[0] < '0' || text[0] > '9') return false;
    char* end = nullptr;
    const unsigned long value = std::strtoul(text, &end, 10);
    if (*end != '\0' || value == 0 || value > UINT32_MAX) return false;
    output = static_cast<std::uint32_t>(value);
    return true;
}
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
extern "C" void app_main() {
    ESP_ERROR_CHECK(nvs_flash_init());
    ESP_ERROR_CHECK(esp_netif_init());
    ESP_ERROR_CHECK(esp_event_loop_create_default());
    rabbit::esp32::initialise_lcd();
    rabbit::esp32::show_lcd_status("STARTING", "--");
    transport.initialise();
    rabbit::protocol::Frame startup_status{};
    const bool link_ready = transport.status(startup_status);
    std::printf("Rabbit RP2350 UART link: %s\n", link_ready ? "ready" : "unavailable");
    start_wifi();
    start_http_server();
    rabbit::esp32::start_wifi_provisioning();
    if (xTaskCreate(lcd_status_task, "rabbit_lcd_status", 4096, nullptr, 4, nullptr) != pdPASS) {
        std::puts("Rabbit LCD status task could not be started");
    }
}

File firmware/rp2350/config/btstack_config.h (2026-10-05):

#ifndef _PICO_BTSTACK_BTSTACK_CONFIG_H
#define _PICO_BTSTACK_BTSTACK_CONFIG_H

// BTstack features that can be enabled
// Classic A2DP source, fixed buffers; no BLE or stdin.
#define ENABLE_LOG_ERROR
#define ENABLE_PRINTF_HEXDUMP
#define ENABLE_SCO_OVER_HCI

#ifdef ENABLE_BLE
#define ENABLE_GATT_CLIENT_PAIRING
#define ENABLE_L2CAP_LE_CREDIT_BASED_FLOW_CONTROL_MODE
#define ENABLE_LE_CENTRAL
#define ENABLE_LE_DATA_LENGTH_EXTENSION
#define ENABLE_LE_PERIPHERAL
#define ENABLE_LE_PRIVACY_ADDRESS_RESOLUTION
#define ENABLE_LE_SECURE_CONNECTIONS
#define ENABLE_LE_ENHANCED_CONNECTION_COMPLETE_EVENT
#endif

#ifdef ENABLE_CLASSIC
#define ENABLE_L2CAP_ENHANCED_RETRANSMISSION_MODE
#define ENABLE_GOEP_L2CAP
#endif

#if defined (ENABLE_CLASSIC) && defined(ENABLE_BLE)
#define ENABLE_CROSS_TRANSPORT_KEY_DERIVATION
#endif

// BTstack configuration. buffers, sizes, ...
#define HCI_OUTGOING_PRE_BUFFER_SIZE 4
#define HCI_ACL_PAYLOAD_SIZE (1691 + 4)
#define HCI_ACL_CHUNK_SIZE_ALIGNMENT 4
#define MAX_NR_AVDTP_CONNECTIONS 1
#define MAX_NR_AVDTP_STREAM_ENDPOINTS 1
#define MAX_NR_AVRCP_CONNECTIONS 2
#define MAX_NR_BNEP_CHANNELS 1
#define MAX_NR_BNEP_SERVICES 1
#define MAX_NR_BTSTACK_LINK_KEY_DB_MEMORY_ENTRIES  2
#define MAX_NR_GATT_CLIENTS 1
#define MAX_NR_HCI_CONNECTIONS 2
#define MAX_NR_HID_HOST_CONNECTIONS 1
#define MAX_NR_HIDS_CLIENTS 1
#define MAX_NR_HFP_CONNECTIONS 1
#define MAX_NR_L2CAP_CHANNELS  4
#define MAX_NR_L2CAP_SERVICES  3
#define MAX_NR_RFCOMM_CHANNELS 1
#define MAX_NR_RFCOMM_MULTIPLEXERS 1
#define MAX_NR_RFCOMM_SERVICES 1
#define MAX_NR_SERVICE_RECORD_ITEMS 4
#define MAX_NR_SM_LOOKUP_ENTRIES 3
#define MAX_NR_WHITELIST_ENTRIES 16
#define MAX_NR_LE_DEVICE_DB_ENTRIES 16

// Limit number of ACL/SCO Buffer to use by stack to avoid cyw43 shared bus overrun
#define MAX_NR_CONTROLLER_ACL_BUFFERS 3
#define MAX_NR_CONTROLLER_SCO_PACKETS 3

// Enable and configure HCI Controller to Host Flow Control to avoid cyw43 shared bus overrun
#define ENABLE_HCI_CONTROLLER_TO_HOST_FLOW_CONTROL
#define HCI_HOST_ACL_PACKET_LEN 1024
#define HCI_HOST_ACL_PACKET_NUM 3
#define HCI_HOST_SCO_PACKET_LEN 120
#define HCI_HOST_SCO_PACKET_NUM 3

// Link Key DB and LE Device DB using TLV on top of Flash Sector interface
#define NVM_NUM_DEVICE_DB_ENTRIES 16
#define NVM_NUM_LINK_KEYS 16

// We don't give btstack a malloc, so use a fixed-size ATT DB.
#define MAX_ATT_DB_SIZE 512

// BTstack HAL configuration
#define HAVE_EMBEDDED_TIME_MS

// map btstack_assert onto Pico SDK assert()
#define HAVE_ASSERT

// Some USB dongles take longer to respond to HCI reset (e.g. BCM20702A).
#define HCI_RESET_RESEND_TIMEOUT_MS 1000

#define ENABLE_SOFTWARE_AES128
#define ENABLE_MICRO_ECC_FOR_LE_SECURE_CONNECTIONS

// Automatic discovery; no stdin dependency.

// To get the audio demos working even with HCI dump at 115200, this truncates long ACL packets
//#define HCI_DUMP_STDOUT_MAX_SIZE_ACL 100

#endif // _PICO_BTSTACK_BTSTACK_CONFIG_H

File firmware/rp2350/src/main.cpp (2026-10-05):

#include <cstdint>
#include <cstdio>
#include <cstring>

#include "hardware/gpio.h"
#include "hardware/uart.h"
#include "hardware/watchdog.h"
#include "hardware/structs/scb.h"
#include "pico/stdlib.h"

#include "rabbit/rp2350/board_config.hpp"
#include "rabbit/rp2350/audio_output.hpp"
#include "rabbit/rp2350/uart_workout_link.hpp"
#include "rabbit/rp2350/ws2812_dma.hpp"

extern "C" void rabbit_hardfault_record(const std::uint32_t* frame) {
    watchdog_hw->scratch[0] |= 0x80000000U;
    watchdog_hw->scratch[1] = scb_hw->cfsr;
    const auto address = reinterpret_cast<std::uintptr_t>(frame);
    const bool valid_frame = address >= 0x20000000U && address <= 0x20081fe0U &&
        (scb_hw->cfsr & 0x3838U) == 0;
    watchdog_hw->scratch[2] = valid_frame ? frame[6] : 0;
    watchdog_hw->scratch[3] = valid_frame ? frame[5] : 0;
    while (true) __asm volatile("wfi");
}
extern "C" __attribute__((naked)) void isr_hardfault() {
    __asm volatile("tst lr, #4\n"
                   "ite eq\n"
                   "mrseq r0, msp\n"
                   "mrsne r0, psp\n"
                   "b rabbit_hardfault_record\n");
}

namespace {
std::uint32_t recovered_stage = 0, recovered_cfsr = 0, recovered_pc = 0, recovered_lr = 0;
constexpr rabbit::core::Microseconds kAudioTestDurationUs = 150'000;
constexpr rabbit::core::Microseconds kLedChaseIntervalUs = 75'000;

struct Diagnostics {
    char command[24]{};
    std::uint8_t command_size{0};
    bool audio_test_active{false};
    bool led_test_active{false};
    std::uint16_t led_test_pixel{0};
    rabbit::core::Microseconds audio_test_deadline_us{0};
    rabbit::core::Microseconds led_test_deadline_us{0};
};

rabbit::core::PoolProfile transport_pool() {
    rabbit::core::PoolProfile pool{};
    static_cast<void>(pool.name.assign("Controller Pool", 15));
    pool.unit = rabbit::core::DistanceUnit::Yard;
    pool.length_mm = 22'860;
    pool.pixel_count = 1;
    pool.segment_count = 1;
    pool.segments[0] = {0, 0};
    pool.revision = 1;
    return pool;
}

void configure_uart() {
    uart_init(uart0, 115200);
    gpio_set_function(rabbit::rp2350::kEspUartTxPin, GPIO_FUNC_UART);
    gpio_set_function(rabbit::rp2350::kEspUartRxPin, GPIO_FUNC_UART);
    uart_set_hw_flow(uart0, false, false);
}

void print_help() {
    std::puts("commands: help status led audio off");
}

void print_status(
    const rabbit::rp2350::Ws2812Dma& leds,
    const rabbit::protocol::WorkoutService& workout,
    const rabbit::rp2350::UartWorkoutLink& uart_link,
    const bool local_stop_pressed) {
    const auto snapshot = workout.snapshot(0);
    const auto& uart_stats = uart_link.stats();
    std::printf(
        "status state=%u led=%s led_pin=%d audio_pin=%d stop=%s esp=%s uart_rx=%lu uart_req=%lu uart_tx=%lu uart_rsp=%lu\n",
        static_cast<unsigned int>(snapshot.state), leds.enabled() ? "ready" : "disabled",
        rabbit::rp2350::kLedDataPin, rabbit::rp2350::kAudioPin,
        rabbit::rp2350::kLocalStopButtonPin < 0 ? "unconfigured" :
            (local_stop_pressed ? "pressed" : "released"), "external",
        static_cast<unsigned long>(uart_stats.received_bytes), static_cast<unsigned long>(uart_stats.received_frames),
        static_cast<unsigned long>(uart_stats.transmitted_bytes), static_cast<unsigned long>(uart_stats.transmitted_frames));
    std::printf("recovery stage=%08lx cfsr=%08lx pc=%08lx lr=%08lx\n",
        static_cast<unsigned long>(recovered_stage), static_cast<unsigned long>(recovered_cfsr),
        static_cast<unsigned long>(recovered_pc), static_cast<unsigned long>(recovered_lr));
}

void clear_leds(rabbit::rp2350::Ws2812Dma& leds) {
    if (!leds.enabled()) return;
    leds.clear();
    leds.show();
}

void handle_command(
    Diagnostics& diagnostics,
    rabbit::rp2350::Ws2812Dma& leds,
    const rabbit::protocol::WorkoutService& workout,
    const rabbit::rp2350::UartWorkoutLink& uart_link,
    const bool local_stop_pressed,
    const rabbit::core::Microseconds now_us) {
    diagnostics.command[diagnostics.command_size] = '\0';
    if (std::strcmp(diagnostics.command, "help") == 0) {
        print_help();
    } else if (std::strcmp(diagnostics.command, "status") == 0) {
        print_status(leds, workout, uart_link, local_stop_pressed);
    } else if (std::strcmp(diagnostics.command, "led") == 0) {
        if (!leds.enabled()) {
            std::puts("led test unavailable: configure a verified RABBIT_LED_PIN");
        } else {
            diagnostics.led_test_active = true;
            diagnostics.led_test_pixel = 0;
            diagnostics.led_test_deadline_us = now_us;
            std::puts("led chase started; send off to stop");
        }
    } else if (std::strcmp(diagnostics.command, "audio") == 0) {
        if (rabbit::rp2350::kAudioPin < 0) {
            std::puts("audio test unavailable: configure a verified RABBIT_AUDIO_PIN");
        } else {
            diagnostics.audio_test_active = true;
            diagnostics.audio_test_deadline_us = now_us + kAudioTestDurationUs;
            std::puts("audio chirp started");
        }
    } else if (std::strcmp(diagnostics.command, "off") == 0) {
        diagnostics.led_test_active = false;
        diagnostics.audio_test_active = false;
        clear_leds(leds);
        std::puts("diagnostics stopped");
    } else if (diagnostics.command_size != 0U) {
        std::puts("unknown command");
        print_help();
    }
    diagnostics.command_size = 0;
}

void poll_console(
    Diagnostics& diagnostics,
    rabbit::rp2350::Ws2812Dma& leds,
    const rabbit::protocol::WorkoutService& workout,
    const rabbit::rp2350::UartWorkoutLink& uart_link,
    const bool local_stop_pressed,
    const rabbit::core::Microseconds now_us) {
    int next_character = getchar_timeout_us(0);
    while (next_character != PICO_ERROR_TIMEOUT) {
        const char character = static_cast<char>(next_character);
        if (character == '\r' || character == '\n') {
            if (diagnostics.command_size != 0U) {
                handle_command(diagnostics, leds, workout, uart_link, local_stop_pressed, now_us);
            }
        } else if (diagnostics.command_size < sizeof(diagnostics.command) - 1U) {
            diagnostics.command[diagnostics.command_size] = character;
            ++diagnostics.command_size;
        }
        next_character = getchar_timeout_us(0);
    }
}
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

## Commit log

2026-10-05 Integrate Waveshare controllers and persistent Bluetooth speaker audio
    Serve the ESP32-C6 web interface and LCD status over the separate-board UART
    link, including DeckScript plan transfer and workout state reconciliation.
    Add RP2350 A2DP speaker discovery, connection, per-device confirmations and
    persistent saved devices. Apply volume and output changes automatically, and
    send quiet keep-alive pulses during long gaps between workout beeps.
    Validation: both firmware builds, three native sanitizer suites, browser
    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
2026-10-05 Add resin-window enclosure and TPU cable reliefs
    [body_petg.stl, cable_entry_fit_coupon_petg.stl, lid_frame_petg.stl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]
2026-10-06 Match resin housing to Rev D PCB and end cable entries
    [Rabbit_Carrier_RevD.kicad_pcb, body_petg.stl, lid_frame_petg.stl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]
2026-10-06 Center top and bottom cable glands on housing
    [body_petg.stl]
2026-10-06 Add carrier placement references and swimming rabbit asset
    [rabbit_compact_carrier.kicad_pcb]
